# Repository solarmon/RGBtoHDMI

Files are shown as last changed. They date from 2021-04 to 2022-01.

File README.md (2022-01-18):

# RGBtoHDMI
RGBtoHDMI Projects

Various PCB projects based on c0pperdragon's Amiga adapter for hogetlet67's RGBtoHDMI solution to provide a HDMI output from the Denise chip digital signals on Amiga computers.

https://github.com/c0pperdragon/Amiga-Digital-Video

https://github.com/hoglet67/RGBtoHDMI

## Issues and Questions

Any issues or questions, please raise a ticket in the **Issues** section:

https://github.com/solarmon/RGBtoHDMI/issues

## Requirements

* Any Raspberry Pi Zero variant, but please note the following:
 - Raspberry Pi Zero 1.3 (original, no wireless, without a header, typically only one per purchase allowed)
 - Raspberry Pi Zero W (with **Wireless**, no header)
 - Raspberry Pi Zero WH (with **Wireless**, with **Header**)
* HDMI adapter/cable: 
 -The Raspberry Pi Zero comes with a **mini-HDMI** interface.
 - This needs needs to be mounted somewhere on, or passed through, the case.

## Audio not supported

The current RGBtoHDMI solutions do not support audio.

You will need to get audio to the HDMI display using some other method.

## OCS Display Modes Only

Only **OCS** display modes are supported, even when an ECS Denise is used.

**ECS** or **AGA** display modes are **not supported**.

## RGBtoHDMI Firmware for Raspberry Pi Zero

The official RGBtoHDMI firmware for the Raspberry Pi Zero can be downloaded from:

https://github.com/hoglet67/RGBtoHDMI/releases

Extract the zip file to the root of the micro-SD card.

Beta releases from IanSB can be downloaded from: 

https://github.com/IanSB/RGBtoHDMI/releases

These releases are sometimes required for certain features to work.

---
## CPLD Based Designs ##

These CPLD based boards are based on RGBtoHDMI CPLD design by LinuxJedi:

https://github.com/LinuxJedi/AmigaRGBtoHDMI

These don't require a Denise OCS/ECS jumper and have three menu button support.

I have added FF OSD integration support to the board.

A Quick Start Guide for these CPLD boards cane be found at:

https://github.com/solarmon/RGBtoHDMI/wiki/RGBtoHDMI-CPLD-Quick-Start-Guide

### RGBtoHDMI Amiga Denise DIP CPLD Rev 1.1 ###

More details and design files:

Rev 1.1: https://github.com/solarmon/RGBtoHDMI/tree/main/CPLD/RGBtoHDMI%20Amiga%20Denise%20DIP%20CPLD%20Rev%201.1

Rev 1.1 adds an optional additional right-angle push button for BT1.

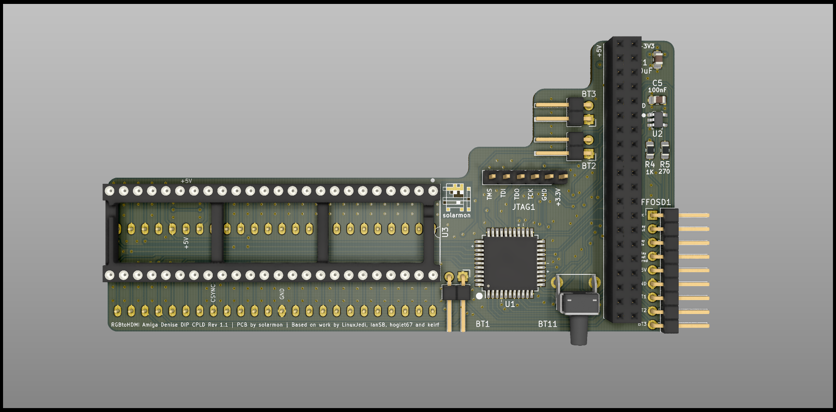
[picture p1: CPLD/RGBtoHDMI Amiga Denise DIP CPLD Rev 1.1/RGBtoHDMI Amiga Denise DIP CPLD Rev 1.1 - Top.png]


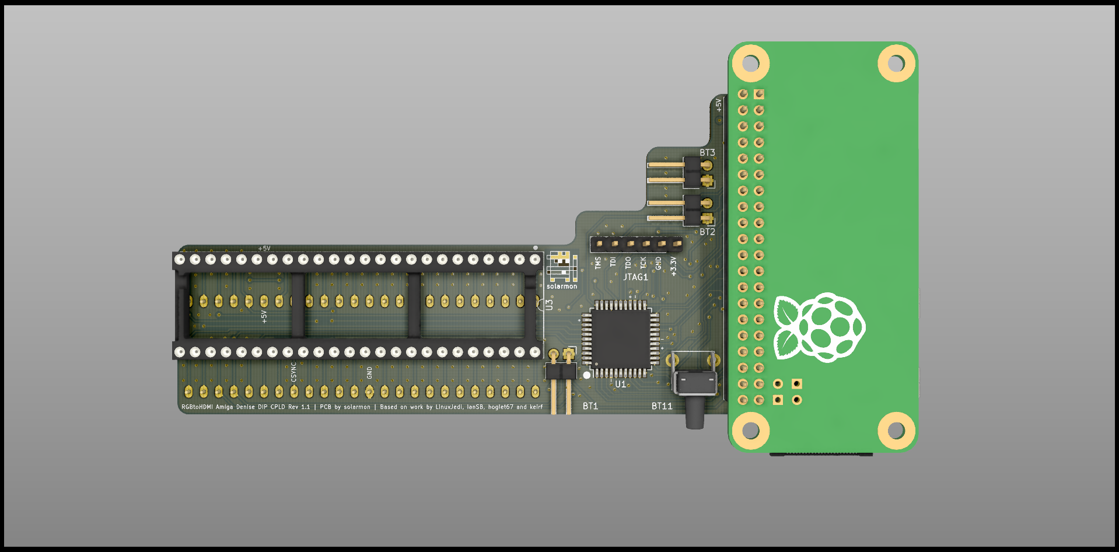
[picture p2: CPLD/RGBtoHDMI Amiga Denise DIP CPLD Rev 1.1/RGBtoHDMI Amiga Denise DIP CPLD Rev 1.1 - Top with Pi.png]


Older revisions:

Rev 1.0: https://github.com/solarmon/RGBtoHDMI/tree/main/CPLD/RGBtoHDMI%20Amiga%20Denise%20DIP%20CPLD

## CPLD and FFC Based Designs ##

These CPLD based boards are based on the excellent RGBtoHDMI CPLD design by LinuxJedi:

https://github.com/LinuxJedi/AmigaRGBtoHDMI

These don't require a Denise OCS/ECS jumper and have three menu button support.

I have added FF OSD integration support to the board.

I have used an FFC connector design to allow for different breakout hats for different Denise packages (PLCC and DIP).

### RGBtoHDMI Amiga Denise CPLD FFC Rev 1.1 ###

More details and design files:

Rev 1.1: https://github.com/solarmon/RGBtoHDMI/tree/main/CPLD/RGBtoHDMI%20Amiga%20Denise%20CPLD%20FFC%20Rev%201.1

Rev 1.1 adds an optional additional right-angle push button for BT1.

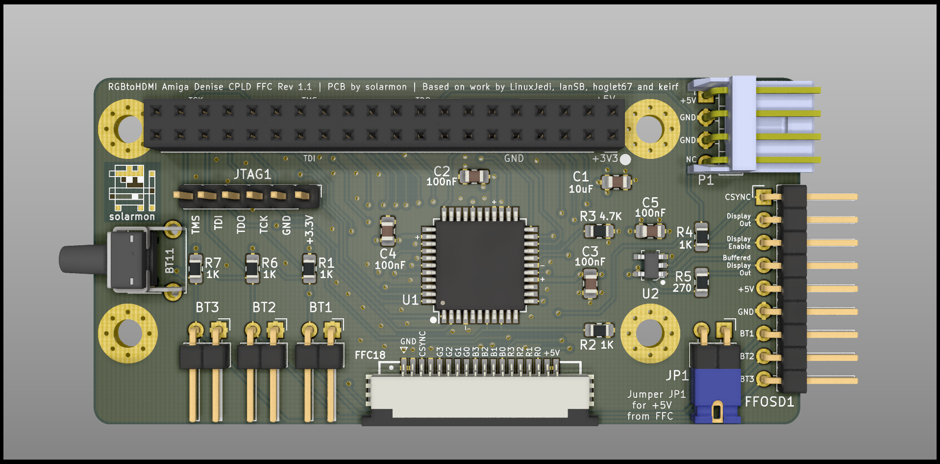
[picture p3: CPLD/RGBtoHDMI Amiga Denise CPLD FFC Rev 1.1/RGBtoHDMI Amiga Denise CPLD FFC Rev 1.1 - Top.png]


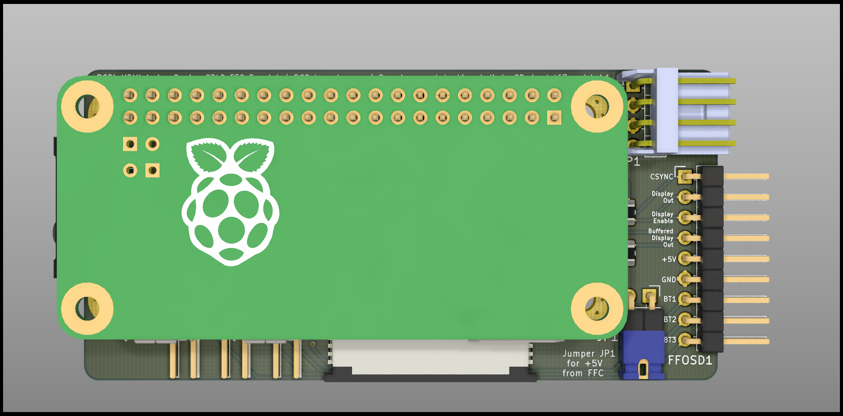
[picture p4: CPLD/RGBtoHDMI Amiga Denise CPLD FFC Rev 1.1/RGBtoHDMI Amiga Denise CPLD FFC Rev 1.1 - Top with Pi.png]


Older revisions:

Rev 1.0: https://github.com/solarmon/RGBtoHDMI/tree/main/CPLD/RGBtoHDMI%20Amiga%20Denise%20CPLD%20FFC

### RGBtoHDMI Amiga Denise PLCC SMT Breakout FFC ###

More details and design files: https://github.com/solarmon/RGBtoHDMI/tree/main/CPLD/RGBtoHDMI%20Amiga%20Denise%20PLCC%20SMT%20Breakout%20FFC

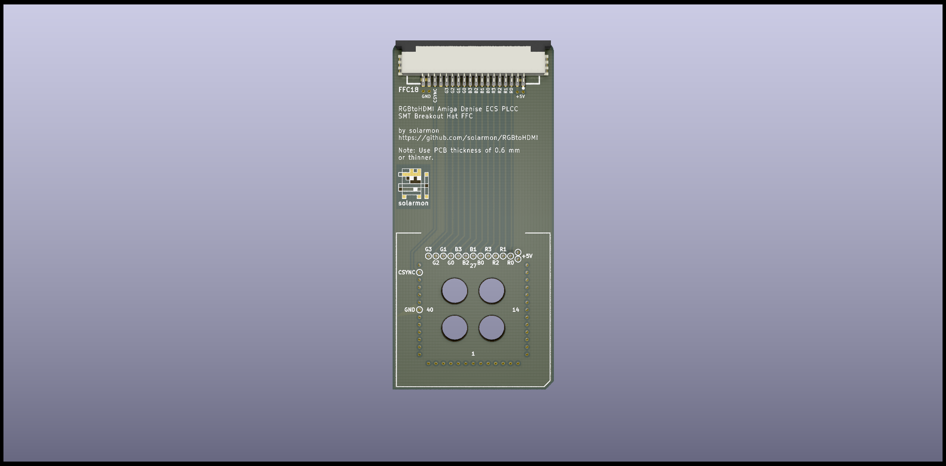
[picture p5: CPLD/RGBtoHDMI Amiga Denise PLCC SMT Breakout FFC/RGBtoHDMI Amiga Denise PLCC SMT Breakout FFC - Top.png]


### RGBtoHDMI Amiga Denise DIP Breakout FFC ###

More details and design files: https://github.com/solarmon/RGBtoHDMI/tree/main/CPLD/RGBtoHDMI%20Amiga%20Denise%20DIP%20Breakout%20FFC

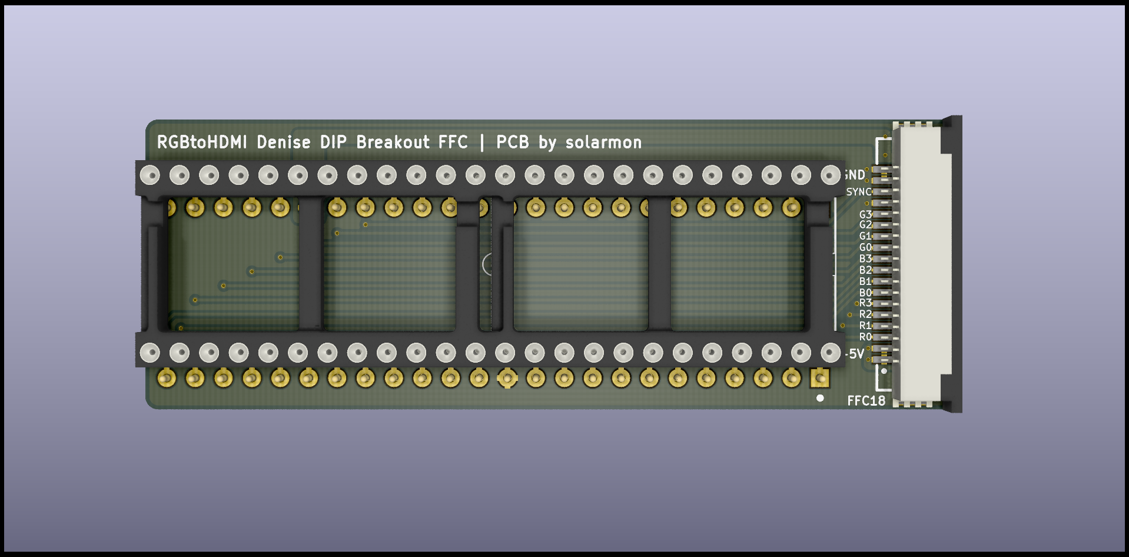
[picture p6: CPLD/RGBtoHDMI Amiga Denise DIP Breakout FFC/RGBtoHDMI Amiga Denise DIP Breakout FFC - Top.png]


### FF OSD Adapter - Rev 2 ##

More details and design files: https://github.com/solarmon/FlashFloppy/tree/main/FF%20OSD%20Adapter%20-%20Rev%202

The CPLD based RGBtoHDMI boards support FlashFloppy OSD integration and this is made easier with the FF OSD Adapter Rev 2 adapter.



---

## Amiga Denise DIP Adapter v2++

KiCAD design files:

https://github.com/solarmon/RGBtoHDMI/tree/main/RGBtoHDMI%20Amiga%20Denise%20-%20v2%2B%2B%20by%20solarmon

Based on on c0pperdragon's v2 adapter

https://github.com/c0pperdragon/Amiga-Digital-Video

https://github.com/hoglet67/RGBtoHDMI/tree/master/kicad_AmigaAdapter/V2



Tweaks and additions:

* Tweak to mask clearances
* Top and bottom ground plane
* Removes +3.3V regulator and uses the Raspberry Pi Zero +3.3V regulator
* Optional delay on PiCLK signal
* Support for FlashFloppy OSD

**Note**: The optional delay circuit (**U4**) for the **PiCLK** signal does not seem to do anything, so it is redundant and not required (but **JP2** still needs to be set to '**Normal PiCLK**'). It will be removed from future versions.

FlashFloppy OSD support is best used with the FlashFloppy OSD Blue Pill adapter at:

https://github.com/solarmon/FlashFloppy/tree/main/FF%20OSD%20Adapter



## Amiga Denise DIP Adapter v2++ Rev 2

KiCAD design files:

https://github.com/solarmon/RGBtoHDMI/tree/main/RGBtoHDMI%20Amiga%20Denise%20-%20v2%2B%2B%20by%20solarmon%20-%20Rev%202





This rev 2 design removes the redundant delay circuit using logic inverters, but adds the option to add a 47pF cap to the PiCLK line.

## Amiga Denise DIP Adapter - With Pi Relocation - Rev 1

**Note:** This is the **Rev 1** design - see further down for the **Rev 2** design.

**WARNING:** Uses an **SMT** socket header for the Raspberry Pi Zero

KiCAD design files:

https://github.com/solarmon/RGBtoHDMI/tree/main/RGBtoHDMI%20Amiga%20Denise%20-%20solarmon

A complete PCB redesign of the Amiga RGBtoHDMI v2 adapter by c0pperdragon.



Features:

* Raspberry Pi relocated to sit above the Odd CIA chip
* Use the Raspberry Pi Zero +3.3V regulator
* Optional delay on PiCLK signal
* Support for FlashFloppy OSD
* Uses an **SMT** socket header for the Raspberry Pi Zero

FlashFloppy OSD support is best used with the FlashFloppy OSD Blue Pill adapter at:

https://github.com/solarmon/FlashFloppy/tree/main/FF%20OSD%20Adapter



**Note**: The optional delay circuit (**U4**) for the **PiCLK** signal does not seem to do anything, so it is redundant and not required (but **JP2** still needs to be set to '**Normal PiCLK**'). It will be removed from future versions.

**Note**: **IMPORTANT** On this board design the Raspberry Pi Zero faces **up**. This is different from the original RGBtoHDMI v2 adapter where it faces **down**. This means the header is on the other side, so any existing Raspberry Pi Zero will need to be modified accordingly. **This will be changed in the next version to face down, so that existing Raspberry Pi Zeros can be used.**



**Note**: This board design still uses the smaller **TSSOP** package from the original RGBtoHDMI adapter. The next version will use the larger **SOIC** package.

## Amiga Denise DIP Adapter - With Pi Relocation - Rev 2 (TSSOP)

**WARNING:** Uses an **SMT** socket header for the Raspberry Pi Zero

KiCAD design files:

https://github.com/solarmon/RGBtoHDMI/tree/main/RGBtoHDMI%20Amiga%20Denise%20-%20solarmon%20-%20Rev%202%20-%20TSSOP

**Note:** This Rev 2 design has the Pi Zero facing **DOWN** (instead of facing **UP** in rev 1)



This rev 2 design removes the redundant delay circuit using logic inverters, but adds the option to add a 47pF cap to the PiCLK line.

This design still uses the smaller **TSSOP** chip package.

## Amiga Denise DIP Adapter - With Pi Relocation - Rev 2 (SOIC)

**WARNING:** Uses an **SMT** socket header for the Raspberry Pi Zero

KiCAD design files:

https://github.com/solarmon/RGBtoHDMI/tree/main/RGBtoHDMI%20Amiga%20Denise%20-%20solarmon%20-%20Rev%202%20-%20SOIC

**Note:** This Rev 2 design has the Pi Zero facing **DOWN** (instead of facing **UP** in rev 1)

**Note:** This version uses the larger SOIC chip package



This rev 2 design removes the redundant delay circuit using logic inverters, but adds the option to add a 47pF cap to the PiCLK line.

This design still uses the larger **SOIC** chip package, making it easier to hand solder.

## Amiga Denise PLCC Adapter

KiCAD design files:

https://github.com/solarmon/RGBtoHDMI/tree/main/RGBtoHDMI%20Amiga%20Denise%20ECS%20PLCC

Based on c0pperdragon's RGBtoHDMI Small adapter.

https://github.com/hoglet67/RGBtoHDMI/tree/master/kicad_AmigaAdapter/Small

This is a PLCC hat version of the RGBtoHDMI Small adapter that sits directly on top of the Denise PLCC chip.

This is for the Amiga A600 Denise ECS chip. However, the RGBtoHDMI solution only supports **OCS** modes, not **ECS** modes:

https://github.com/c0pperdragon/Amiga-Digital-Video#compatibility

**Note**: It uses the larger **SOIC** chip package, rather than the smaller **TSSOP** chip package.



Features:

* No soldering required - sits directly on top of the Denise PLCC chip
* Integrated RGBtoHDMI solution on same board.

**Note**: The +**5V** and **GND** traces going to the Denise PLCC chip is very thin. Header **JP1** is provided for +**5V** and **GND**. It is recommedned that power is provided to the board using this.

**Note**: The PLCC socket on this board needs some midifications to allow it to sit properly. See LemaruX's guide on the 68K PLCC socket rework that also applies to the Denise PLCC socket: 

https://github.com/LemaruX/Amiga-A600-68k-PLCC2DIP-v2/blob/main/PLCC-Rework.md

**Note**: This design will not work with most expansion boards in the A600 as it will spoil with it. Check compatibility before you commit to using/buying this board.

**Note**: On this board, the Raspberry Pi Zero faces **down**:



## RGBtoHDMI Pi Relocator Adapter  - Type A

KiCAD Design Files: https://github.com/solarmon/RGBtoHDMI/tree/main/RGBtoHDMI-Adapter%20Type%20A

This is a Pi relocator adapter that will flip it over to sit over RGBtoHDMI board.

**Note**: **IMPORTANT** The Raspberry Pi Zero is flipped over. To keep the profile low, you need to solder the Raspberry Pi Zero directly to the adapter.





## RGBtoHDMI Pi Relocator Adapter  - Type B Rev 2

KiCAD design Files: https://github.com/solarmon/RGBtoHDMI/tree/main/RGBtoHDMI-Adapter%20Type%20B%20Rev%202

This is a Pi relocator adapter and has an optional 47pF (or other value) location to reduce any sparkles.



## RGBtoHDMI Pi Relocator Adapter  - Type C Rev 2

KiCAD design Files: https://github.com/solarmon/RGBtoHDMI/tree/main/RGBtoHDMI-Adapter%20Type%20C%20Rev%202

This is a Pi relocator adapter and has an optional 47pF (or other value) location to reduce any sparkles.



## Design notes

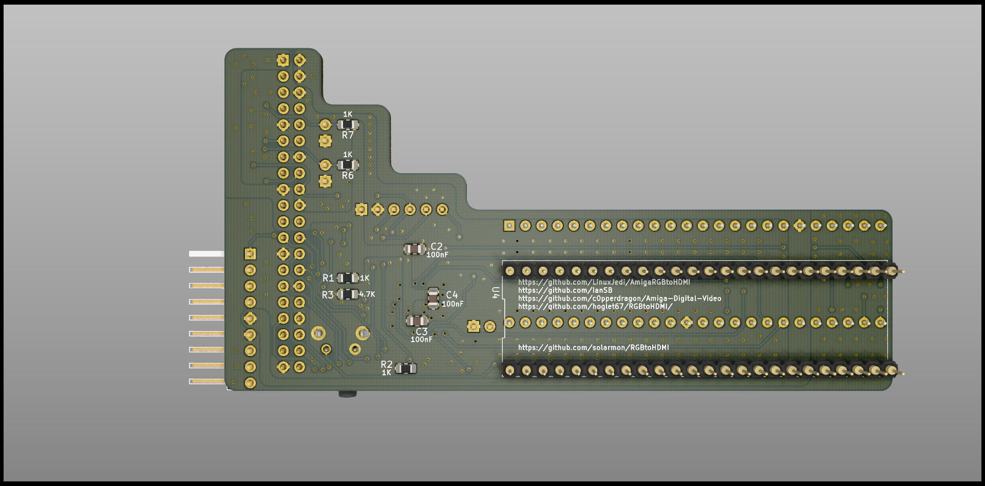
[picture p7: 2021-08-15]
CPLD/RGBtoHDMI Amiga Denise DIP CPLD Rev 1.1/RGBtoHDMI Amiga Denise DIP CPLD Rev 1.1 - Bottom.png

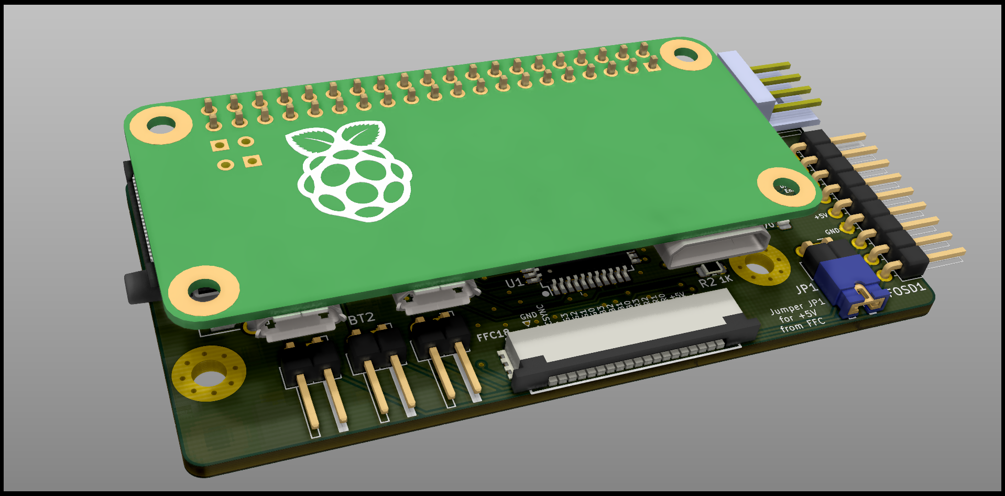
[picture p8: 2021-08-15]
CPLD/RGBtoHDMI Amiga Denise CPLD FFC Rev 1.1/RGBtoHDMI Amiga Denise CPLD FFC Rev 1.1 - Top Angled with Pi.png

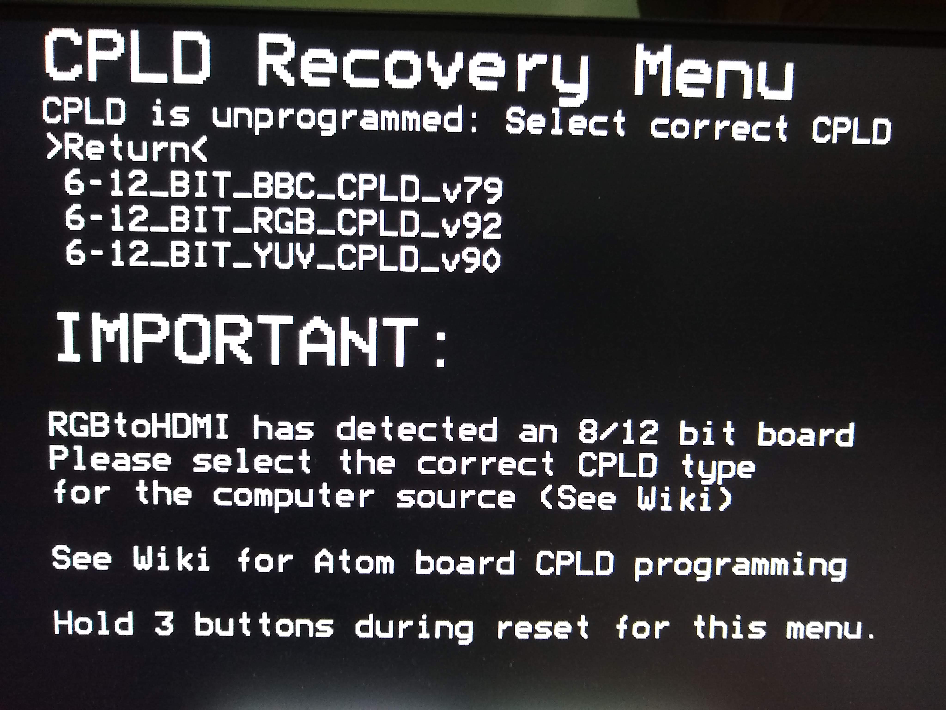
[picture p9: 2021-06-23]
CPLD/CPLD-Recovery-Menu.jpg

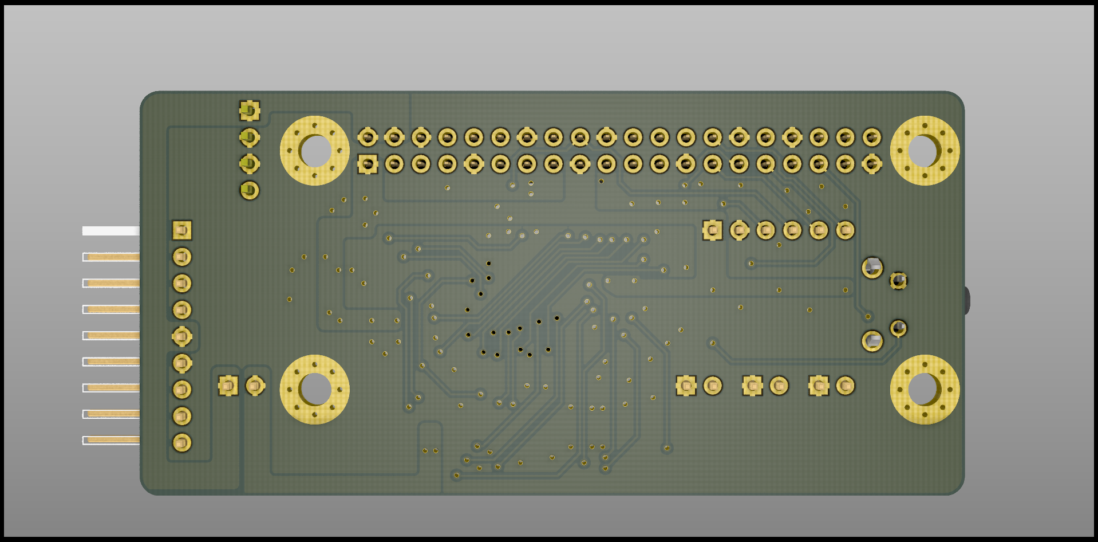
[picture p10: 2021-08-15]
CPLD/RGBtoHDMI Amiga Denise CPLD FFC Rev 1.1/RGBtoHDMI Amiga Denise CPLD FFC Rev 1.1 - Bottom.png

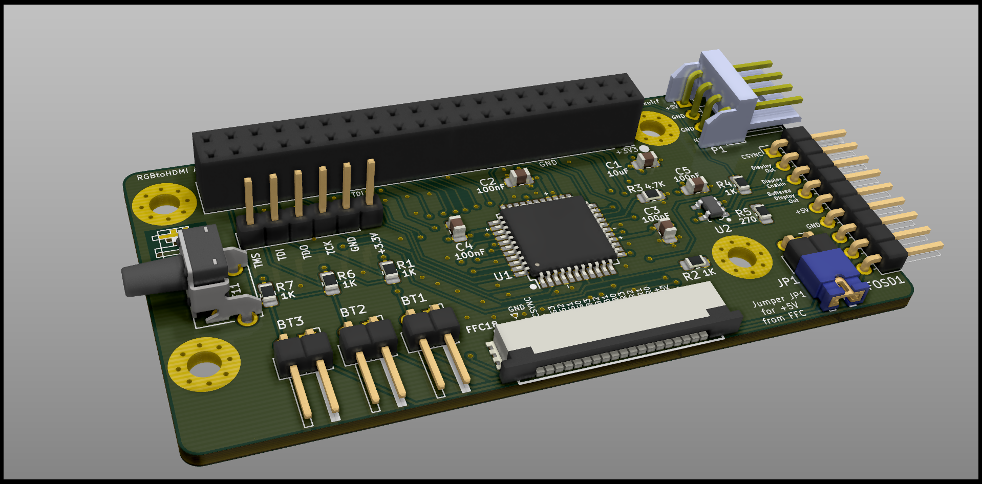
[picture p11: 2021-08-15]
CPLD/RGBtoHDMI Amiga Denise CPLD FFC Rev 1.1/RGBtoHDMI Amiga Denise CPLD FFC Rev 1.1 - Top Angled.png

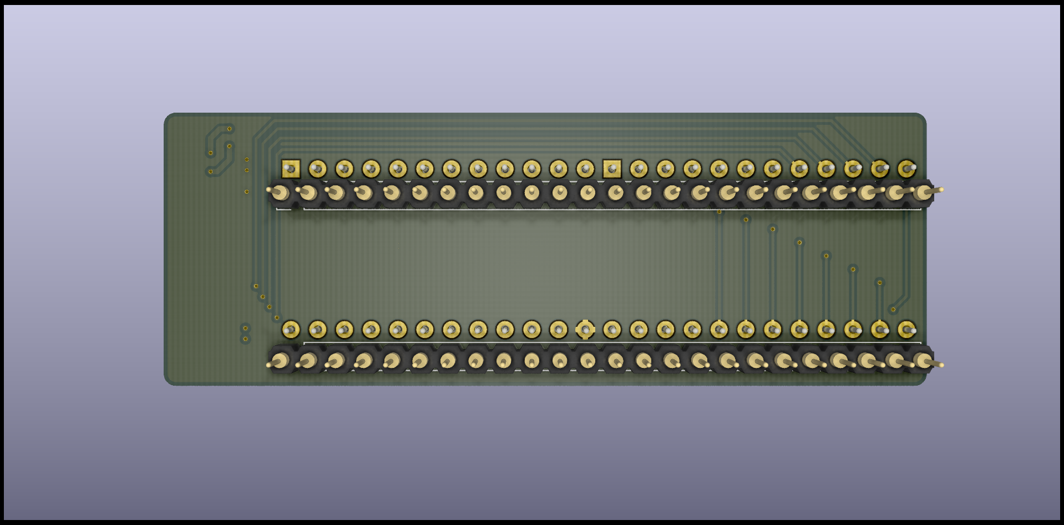
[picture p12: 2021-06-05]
CPLD/RGBtoHDMI Amiga Denise DIP Breakout FFC/RGBtoHDMI Amiga Denise DIP Breakout FFC - Bottom.png

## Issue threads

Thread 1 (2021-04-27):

RGBtoHDMI PLCC model

krug3rf, 2021-04-27:
Hi @solarmon ,

I just made my first model and I have an issue, I just see the splashcreen (4 color from start) and nothing more...
I use a LVC574A**D**, do you think it could be the problem ?!
I don't use P1, but I use a external alimentation for testing, but no change.

KR
Fred

solarmon, 2021-04-28:
Hi @krug3rf

I use the following logic chips on my boards:

U2/U3: Texas Instruments SN74LVC574ADW Octal D Type Flip Flop IC, 3-State, 20-Pin SOIC
U1: Texas Instruments SN74LVC86ADR, Quad 2-Input XOR Logic Gate, 14-Pin SOIC

What is the full part number of your chips?

Can you show how you have built it - especially the PLCC socket - this has to be in the correct orientation.

Use a multimeter to check the identified Denise pins (the ones circled) to where they should be on the motherboard - especially the CSYNC and 7M signals.

krug3rf, 2021-04-28:
All continuties from U1/U2/U3 have been tested and are OK.
I check again to answer when I will back home (I'm at office) ;)

solarmon, 2021-04-30:
@krug3rf Do you still have this issue? If you can provide more information then I can try to help you resolve it.

krug3rf, 2021-04-30:
Hi, I'm back home this weekend and do it ;)
thanks for your help :)

Le ven. 30 avr. 2021 à 09:32, solarmon ***@***.***> a écrit :

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

krug3rf, 2021-04-30:
I have a question for you about the PLCC 52, do you use sandpaper or a hand
tool (like a dremel) to modify it ?
Your model is an Augat PCS-052A or a generic ?

Le ven. 30 avr. 2021 à 10:08, Frédéric Campos ***@***.***> a
écrit :

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

solarmon, 2021-04-30:
@krug3rf For the PLCC-52socket mod, all I did was to cut the plastic standoffs inside the socket. I just use some small wire side cutters, but it is not so good - so a Dremel type tool is probably the better/recommended option.

I don't know what 'model' my PLCC-52 socket is - it is just a no brand one that I purchased on eBay.

krug3rf, 2021-05-01:
Î'm exiting ^^
Can you share some beta previews of your new projects (I keep this for me,
promise :p) ?

Le ven. 30 avr. 2021 à 23:54, solarmon ***@***.***> a écrit :

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

krug3rf, 2021-05-01:
*excited lol

Le sam. 1 mai 2021 à 11:55, Frédéric Campos ***@***.***> a
écrit :

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

solarmon, 2021-05-02:
@krug3rf I can give you some teaser pictures!

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

krug3rf, 2021-05-02:
Sexy ^^
so with this model Furia accelerator could be added ?

Le dim. 2 mai 2021 à 11:57, solarmon ***@***.***> a écrit :

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

solarmon, 2021-05-02:
CPLD solution design is from LinuxJedi, I'm just re-mixing it to a new footprint.

I have not got a Furia accelerator to test, so I don't know if this PLCC FFC hat design will be low profile enough.

Closed 2021-04-30.

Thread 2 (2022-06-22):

Single Button Mode not working

tkurbad, 2022-06-22:
Hi,

I built one of these boards and it's working perfectly so fine. The problems I had with the original design (i.e. purple sparkles) are gone. Picture is crisp and clear.

However, I can't get single button mode to work as expected. It seems inverted, i.e. a long press turns on/off scanlines, while a short press displays the OSD. However, while the OSD is showing, the next press is always considered short, thus closing the OSD again.

Here's my Profiles/Default.txt

``
sampling2=6,6,6,6,6,6,6,0,1,0,12,0,0,0,0,0,0,0,0,0,100,256,100,256,100,256,256,256
geometry2=140,26,520,256,576,288,3,4,1,0,12000000,768,5000,312,4,0,2
sampling=3,3,3,3,3,3,3,0,0,0,5,0,0,0,0,0,0,0,0,0,100,256,100,256,100,256,256,256
geometry=180,29,640,256,768,288,1,2,1,1,16000000,1024,5000,312,4,0,0
auto_switch=0
timing_set=0
palette=RGB
palette_control=0
ntsc_colour=0
ntsc_phase=0
ntsc_quality=0
tint=0
saturation=100
contrast=100
brightness=100
gamma=100
teletext_deinterlace=6
teletext_scaling=1
normal_deinterlace=0
ffosd_overlay=0
normal_scaling=0
swap_aspect=0
output_colour=0
output_invert=0
scanlines=0
scanline_level=6
powerup_message=1
crop_border=0
screencap_size=0
border_colour=0
font_size=1
vsync_indicator=0
genlock_mode=0
genlock_line=50
genlock_speed=2
genlock_adjust=0
num_buffers=0
hdmi_standby=0
overclock_cpu=0
overclock_core=0
overclock_sdram=0
button_reverse=0
debug=0
keymap=13232
actionmap=012453
return=0
single_button_mode=1
cpld_firmware_dir=/cpld_firmware/6-12_bit
``

Can you tell what might be wrong? This happens on both stable and beta releases.

Thanks,
Torsten

tkurbad, 2022-06-22:
Okay, nevermind, it's working perfectly fine. Just saw that I edited the wrong Default.txt ;-)

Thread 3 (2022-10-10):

Rev 2 board doesn't fit on Rev 3 Amiga 500 motherboards

MatGrump, 2022-10-10:
The inductor LF1 is lower on Rev 3 boards and doesn't allow for installation of the REV 2 RGD2HDMI board. See attached images

https://imgur.com/a/YwSwP5C

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

solarmon, 2022-10-10:
Hi,

That is not one of my RGBtoHDMI board for the A500.

It looks like it is from PM Developments:

https://www.facebook.com/PMDevelopments/
https://www.instagram.com/pmdevelopments/

You'll have to raise that with that developer.

MatGrump, 2022-10-10:
yes sorry. I noticed after i posted it. It looks like yours has taken this into consideration.

solarmon, 2022-10-10:
No worries. I can't remember whether I actually tested with a rev 3 board - I'll have to dig it out to check!

MatGrump, 2022-10-10:
No problem, if you need me to measure anything please let me know.

solarmon, 2022-10-10:
Actually, I don't have a rev 3. I was thinking of a rev 5, which I do have.

Using an image I found of the rev 3, I overlayed an image of my latest RGBtoHDMI A500 board, and that looks like it wouldn't fit either:

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

The coil is definitely much lower in a rev 3 board!

I can think of three options you might have:

1. Use the original RGBtoHDMI board design, which doesn't have a pi relocator.

2. Use my RGBtoHDMI Amiga Denise CPLD FFC Rev 1.1 (https://github.com/solarmon/RGBtoHDMI#rgbtohdmi-amiga-denise-cpld-ffc-rev-11) with a RGBtoHDMI Amiga Denise DIP Breakout FFC (https://github.com/solarmon/RGBtoHDMI#rgbtohdmi-amiga-denise-dip-breakout-ffc).

3. Replace the Denise socket on the RGBtoHDMI board with ones with longer pins that pass straight through. This shift down the board a bit, which MIGHT work. I use such a socket for my RGBtoHDMI CDTV solution and it also makes it a bit lower profile.

solarmon, 2022-10-10:
The latest LinuxJedi design, looks like it should support rev 3 motherboards:

MatGrump, 2022-10-10:
Some good solutions. I have the option to return this board and get another which is probably what I will do for now while I think about a different solution. The LinuxJedi looks like the simplest way forward but they are out of stock.

Thanks for all the help, even though it wasn't even your board. Very much appreciated.

Retrofletch, 2022-11-21:
I made a longer version based on the old linuxjedi version that i think also would fit.
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

and there is also this version that should fit:
https://github.com/nobodyisinocent/RGBtoHDMI#tiny-rgb2hdmi-cpld-design-

Just for future reference :)

ehalebi, 2023-08-19:
@solarmon is it possible to make a Extralong version of CPLD 500 PCB with your FF addons? Retrofletch has one, but without FF OSD support.

regards

Retrofletch, 2023-08-19:
It would be quite easy to make solarmons design a bit longer to fit but i just dont have the time at this moment

ehalebi, 2023-08-19:
@solarmon is that something you could do?
Maybe 5-8cm longer. So a lot of people got a Gotek drive and want to add also HDMI to their A500s. And if you also got an accelerator card sitting on a 90 degree Relocator, than this will be the best RGB2HDMI Solution .

only thing missing is still audio embedder/injector for all of them.

ehalebi, 2023-08-19:
I have bought an audio Inserter for installing it internally in my A500
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

solarmon, 2023-08-19:
@ehalebi

It can certainly be done, but unfortunately, this is not high my list (if at all). Probably the only reason I would work on this again, is to create a PLCC version of it.

Regards,

Mon

ehalebi, 2023-09-11:
Do I need to buy software to do this?

regards

solarmon, 2023-09-12:
@ehalebi

> Do I need to buy software to do this?
>
> regards

To do what?

solarmon, 2023-09-12:
@ehalebi

The PCB design was done using KiCAD, which is an open source application - https://www.kicad.org/

But be warned - it is a very steep learning curve if you don't already have experience in PCB design.

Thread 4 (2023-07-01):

Getting a no sync issue

luvwagn, 2023-07-01:
I'm wondering if instructions are still correct, regarding the amiga_cpld folder etc.

My cdtv rgbtohdmi is working, amiga is working via db23 video port, but I can't get a sync signal?

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

solarmon, 2023-07-02:
Hi,

For the purpose of this ticket, please provide some context:

* What RGBtoHDMI adapter have you got?
* Where did you buy it from (or whether you built it yourself)?
* Which Amiga it is being used on, and what Denise chip does it have?

Please provide some clear pictures of your RGBtoHDMI board/adapter and setup.

luvwagn, 2023-07-02:
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

None of the above results in a solid image, but I can see the content changing from cdtv insertion animation, to wb3.2.x (ntsc mode)
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

Retrofletch, 2023-07-05:
I sent him a copy of my own SD card i use for testing these, it will help rule out issue with his software setup.
I also asked him to test contuinity between csync on both ribbon cable connectors to rule out bad cable / connection.
if these are not issue im gonna assume i borked something up hardware wise, i always test before send ofcourse but it could have been a badly soldered connection or similar that got loose in shipping or while installing. it happens =/

solarmon, 2023-07-05:
@luvwagn

Apologies for the delay in replying.

For the Denise adapter FFC connector, it looks different my normal design - which has the contacts at the bottom - so the FFC flex cable has the contacts at the bottom and the blue side facing up (maybe @Retrofletch can confirm). This also the same at the RGBtoHDMI board end too.

luvwagn, 2023-07-05:
As mentioned in email, it depends on the connectors. With blue up at both ends, I get a black screen. With blue down at both ends, I get some correct  but garbled output.

Your design has the cables under black connectors and blue up, but different choice of connectors like used here means black underneath and blue down.

solarmon, 2023-07-06:
@luvwagn

All I can suggest is to check the flex connector pins on the Denise adapter and on the RGBtoHDMI board; and also check the pins on the CPLD chip- check that there are no cold joints and they are not shorted together.

luvwagn, 2023-07-28:
@solarmon - the fw releases from Ian / hoglet etc have an "Amiga_CPLD" folder - is any action required regarding that folder, on your design?  It references "LinuxJedi" designs as needing things done regarding that folder...

luvwagn, 2023-07-28:
> @luvwagn
>
> All I can suggest is to check the flex connector pins on the Denise adapter and on the RGBtoHDMI board; and also check the pins on the CPLD chip- check that there are no cold joints and they are not shorted together.

Have done so - there is full CSYNC continuity between the denise pin, ribbon header on Denise Board, and ribbon header on RGB2HDMI board.  Checked other connections as well, have full continuity

solarmon, 2023-07-28:
@luvwagn

Please point to where it "needing things done regarding that folder" - I'm not sure what you mean.

You seem to have the software running correctly - so I'm not suspecting that. It just seems the signal to/from the CPLD chip is possibly shorted or not connected somewhere. Sorry, there is nothing else I can suggest.

luvwagn, 2023-07-28:
There is an amiga_cpld_readme folder at the root of the zip file.  it doesn't matter if i perform those actions or not, i get the same "no sync found" problem.  I believe those actions just set the defaults to 1-button mode and an Amiga setting.

I checked the CSYNC signal from U1 Pin 3+4 to Denise to Denise Carrier PCB with ribbon connector, to RGB2HDMI board, to CPLD pin.  I have continuity through the entire path.

Is it possible somehow that CSYNC is incorrect?  That doesn't make sense to me, as regular RGB output is working...
________________________________
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

Retrofletch, 2023-09-06:
It works just fine but i tend to respond only once i have an update, you can also reach me by mail retrofletch@outlook.com so we dont annoy solarmon by all this offtopic.

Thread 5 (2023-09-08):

pixelation issues with rgb2hdmi board

pruttm, 2023-09-08:
I have installed the rpg2hdmi board below in my Rev 5 Amiga 500.  The display has incorrect pixels sprinkled over the display and some of them flash.  I also noticed the display can change when I press on the Denise chip. I could order some contact cleaner if it is a connectivity issue. Alternatively, are there settings I should be adjusting to clear this up?

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

solarmon, 2024-11-03:
@pruttm

Sorry, I've only just seen this ticket.

Where did you purchase this RGBtoHDMI board from, and which exact model/version?

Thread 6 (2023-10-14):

RPi not booting with CPLD RGB to HDMI

bmthr, 2023-10-14:
Hi all,

My problem is that my RPi ZERO WH not working wiith CPLD RGB to HDMI adapter on Amiga 500. RPi 1.3 work well with this adapter and RPi WH working well with TTL adapter.
RPi WH if not connected to CPLD adapter board show menu _CPLD not fitted_, but when I connect it to CPLD board stuck on empty black screen.

Did I miss some settings? Any help about my problem?

Thank You!

bmthr, 2023-10-16:
I build it by myself, I build almost 200 boards TTL and CPLD and necet found problem like this...

Pictures if CPLD board and RPi attached...
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

bmthr, 2023-10-16:
When I connect all to Amiga, screen is black, there is no any message or info on screen. If I connect only RPi to HDMI and connect power supply I get message CPLD not fitted. As I say before, when I put this RPi to Small TTL RGBtoHDMI adapter all is working well

solarmon, 2023-10-16:
Hi @bmthr

This is not one of my RGBtoHDMI board designs - it is one from LinuxJedi.

Normally, when I have issues with the a CPLD based RGBtoHDMI board, it is because there is a cold solder joint on one of the pullup resistors or capacitors, or (a cold joint or short) on a CPLD pin.

bmthr, 2023-10-16:
Yes, I know that, but I tested this Rpi with other CPLD board (have it 3 on stock now) and problem is same, but all boards work fine with RPi v1.3

solarmon, 2023-10-16:
What RGBtoHDMI firmware version are you using?

Get the latest stable version from:

https://github.com/hoglet67/RGBtoHDMI/releases

or the latest beta versions from:

https://github.com/IanSB/RGBtoHDMI/releases

I've have also come across issues where the CPLD RGBtoHDMI board did not work until you tried a different microSD card on the Pi.

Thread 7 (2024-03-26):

STM Binary

venice1200, 2024-03-26:
Hi,
I am going to build your RGB2HDMI FlashFloppy OSD Project but I don’t know how to build the firmware for the STM.

Is there a prebuild binary available from your end?

And do you have any plans plans to patch the current OSD Version from keirf with your changes?

Many Thanks

solarmon, 2024-03-26:
Hi,

Do you mean my forked repo for OSD at?:

https://github.com/solarmon/FF_OSD

If I remember correctly, the only change I did was to add the RGBtoHDMI 3-button example (in https://github.com/solarmon/FF_OSD/blob/master/src/default_config.c):

https://github.com/solarmon/FF_OSD/commit/b5f8fc9119af0d06347212f83702bbfb92cdf91b

So you could probably easily make this change to the source file of the original repo at https://github.com/keirf/flashfloppy-osd

Sorry, I don't have any pre-built binaries. I can't even remember how to build it without looking in to it again.

solarmon, 2024-03-26:
The build guide from keirf's flashfloppy-osd repo is at:

https://github.com/keirf/flashfloppy-osd/wiki/Building-From-Source

venice1200, 2024-03-27:
...means the RGB2HDMI OSD via HDMI works out of the box when i build and use your hardware, even with an unmodified Software from keirf?

solarmon, 2024-03-27:
Well, it will work but without the three button integration - so you cannot use the keyboard to control the RGBtoHDMI menu (using F1, F2 and F3 - or whatever button you assign in `default_config.c`)

solarmon, 2024-03-27:
I have updated the README (for https://github.com/solarmon/FlashFloppy/tree/main/FF%20OSD%20Adapter%20-%20Rev%202) to mention the button mapping changes required, and link to how to build the Blue Pill firmware:

https://github.com/solarmon/FlashFloppy/blob/main/FF%20OSD%20Adapter%20-%20Rev%202/README.md#ff-osd-firmware

venice1200, 2024-03-27:
I will try!

Many Thx

venice1200, 2024-04-02:
Hi again,
C1 is marked as Unipolar 10uF Capacitator. But the footprint picture looks like a "normal" Ceramic one.
Is a bipolar one fine as well?

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

Are all SMD Parts 0805?

Cheers

venice1200, 2024-05-05:
I got the boards and the CPLD and the other parts solderred.
I have checked every conection to the PI, everthing looks fine, but the CPLD can't be programmed.

```
8/12 bit board detected
...
CPLD  Design: 3-12_BIT_BBC
CPLD Version: c.f
```
Any idea what can be the problem?

Full log attached.

[2024-05-05_Serial_Log.txt](https://github.com/solarmon/RGBtoHDMI/files/15213682/2024-05-05_Serial_Log.txt)

solarmon, 2024-05-05:
Hi,

Which RGBtoHDMI board did you build?

Check that non of the CPLD chip pins are shorted or have dry connections. Also check the resistors and caps are OK and connected to where they should be.

venice1200, 2024-05-05:
I built a Denise Adapter v1.1.

I have already checked the whole board as good as possible.

solarmon, 2024-05-05:
Which CPLD chip are you using - what is the exact part number and where did you get it from?

IanSB, 2024-05-05:
@solarmon

The CPLD is already programmed with some other firmware. The fix on a normal CPLD board is to cut JP1, JP2 & JP4 for first programming and then remake them. Are those jumpers present on your board?

solarmon, 2024-05-05:
@IanSB

Unfortunately, there are no such jumpers on my board design - so those tracks will need to be physically cut.

venice1200, 2024-05-06:
I am using a XC9572XL VQFP44.

TCK (44), TMS (6) and TDI (7) are connected to a dedicated PinHeader in the board.

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

@IanSB
maybe we can drive the pins up or down for reprogramming?

solarmon, 2024-05-06:
For my own future reference - details of the solder jumpers (bridged)  and what pins/signals they are for:

JP1 = GPI00 = TDI
JP2 = GPI020 = TCK
JP4 = GPI01 = TMS

These don't currently exist on any of my RGBtoHDMI board designs.

venice1200, 2024-05-06:
I think the Pins which needs to be disconnected are TCK (44), TMS (6) and TDI (7).
Not the other three pins.

Please correct me if i am wrong.

IanSB, 2024-05-06:
@venice1200
@solarmon

The pins that have to be disconnected are CLKEN, SPDATA and SPCLK which are Pins 6, 7 and 44 of the CPLD.
You have to cut the tracks going to those pins without breaking the connection between the GPIOs and TCK, TMS and TDI
Depending on the layout, this might not be easy as the tracks might be under the CPLD or cutting them also disconnects the GPIOS from the TCK, TMS and TDI pins.
The other option would be to temporarily desolder and bend up CPLD pins 6, 7 and 44.

IanSB, 2024-05-08:
@solarmon
I suggest you add those jumpers to any future revisions of your boards.
Any reason you didn't include them? The jumpers were originally added when CPLD programming was added to the project in case users accidentally programmed the Atom firmware which has the same effect but it has been useful for coping with recycled CPLDs

I have updated the wiki to cover this in more detail including how to use the 'Delete_This_File_To_Erase_CPLD.txt' feature:
https://github.com/IanSB/RGBtoHDMI/wiki/Troubleshooting

This is likely the cause of the problem with this issue too:  https://github.com/solarmon/RGBtoHDMI/issues/6

BTW can you give the latest Alpha 65G a test to see if it works with your monitor(s). It contains a HDMI audio output driver but no audio input yet!
https://github.com/IanSB/RGBtoHDMI/issues/29#issuecomment-2099613155

solarmon, 2024-05-08:
> @solarmon I suggest you add those jumpers to any future revisions of your boards. Any reason you didn't include them? The jumpers were originally added when CPLD programming was added to the project in case users accidentally programmed the Atom firmware which has the same effect but it has been useful for coping with recycled CPLDs
>

My RGBtoHDMI spinoffs were original based on the c0pperdragon and LinuxJedi designs, which didn't have these jumpers. And this is the first I've heard of this specific issue.

> BTW can you give the latest Alpha 65G a test to see if it works with your monitor(s). It contains a HDMI audio output driver but no audio input yet! [IanSB/RGBtoHDMI#29 (comment)](https://github.com/IanSB/RGBtoHDMI/issues/29#issuecomment-2099613155)

Ooh, that is interesting! I will definitely try it and will report back on that ticket.

venice1200, 2024-05-08:
Success...

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

IanSB, 2024-05-08:
@venice1200
That's great

@solarmon
> And this is the first I've heard of this specific issue.

It seems to be getting more common, as you can see from the above photo I added a message about it to the latest release although that doesn't help so much if you just get a blank screen and don't know about the three buttons or the delete file.

One other thing that just occurred to me:
There was originally a jumper JP3 which isolated the fourth programming line TDO but the additional CPLD pin it was connected to was re-used for something else and TDO is connected straight to GPIO 24 on the current revision.
However GPIO24 is now also used for the FFOSD overlay so you need to make sure that is disconnected when programming the CPLD.

solarmon, 2024-05-08:
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

Yea, this RGBtoHDMI board integrates with FF-OSD and this overlay connection is basically how FF-OSD feeds it's OSD menu to the Pi to be put into the HDMI display.

IanSB, 2024-05-08:
@venice1200
@solarmon
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
venice1200, 2024-07-02:
Hi,
finally i added all your RGBtoHDMI Boards and programmed the BluePil with the original Hex from keirf (for the moment).
But I get no OSD shown.

Question, do I need the green line from the BluePil Board to the Amiga to get the OSD shown?

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

venice1200, 2024-07-02:
I have tried with PA15 Low enabled but no success.

```
** FF OSD v1.9 **
** Keir Fraser <keir.xen@gmail.com>
** https://github.com/keirf/FF_OSD

Current config:
 Sync Polarity: Low
 Pixel Timing: 15kHz
 Display Height: Normal
 Display Output: PB15/SPI2
 Display Enable: PA15 Act.LOW
 H.Off: 42
 V.Off: 50
 Rows: 2
 Columns: 16-40

Keys:
 Space: Select
 O: Down
 P: Up
Sync lost
```

solarmon, 2024-07-03:
Hi @venice1200

You shouldn't need the RGB output signal to be connected. However, it is useful to see/check whether FF OSD is actually working on your Bluepill.

solarmon, 2024-07-03:
@venice1200

On your FF OSD Adapter board, have you got JP1 jumpered?

venice1200, 2024-07-03:
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

Yes.

venice1200, 2024-07-03:
Got it working!
Had to add a jumper at JP2 between sync (middle) and c/h sync.

Should this looks like this?
The chars look like flames.

https://github.com/solarmon/RGBtoHDMI/assets/43762187/f85cd49a-4581-460f-b4e8-a341047465d7

solarmon, 2024-07-03:
Glad you figured it out.

Unfortunately, that is the best that the FF OSD will look over the HDMI output.

venice1200, 2024-07-03:
Many man thanks for your support and all the best!

IanSB, 2024-07-03:
@venice1200

The reason it's jittery is that the pixel clock of the blue pill isn't locked to the Amiga pixel clock so it was either that or nothing.
In theory you could run the blue pill from an Amiga derived clock which would stop the jittering but so far no-one has looked at that.

solarmon, 2024-07-03:
@IanSB

Would that be a software or hardware thing, or both - to get the Blue Pill to use the Amiga clock?

venice1200, 2024-07-04:
Additionally I get problems reading data from the gotek.

Data are not correctly loaded each time.
If this happens the screen shows then below system request and the gotek is sent to the eject menu.

If remove the bluepil board it works fine again.

It can be my installation, i need to test more.

I am using flash floppy 3.42.

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

solarmon, 2024-07-04:
@venice1200

I can't seen how the Bluepill with FF OSD software could interfere with the FF on the Gotek reading ADF files.

The only connection between the Bluepill and Gotek should be the GND, 3.3V, SCL and SDA lines for I2C communications.

If it is causing FF on the Gotek to eject the ADF image then that might suggest that keyboard binding integration part is possibly interfering with it - so check the KB_CLOCK anf KB_DATA connections, and make sure you use a FF OSD firmware that supports the keyboard integration.

venice1200, 2024-07-04:
The Keyboard integration works fine for me, no problems here.

I can't tell you what causes this.

The only thing i know is that it works (for me) only without the bluepil board connected but let me a few more things.

Do you have a running OSD integration in use actually?

venice1200, 2024-07-07:
I have changed the display to another one, no change.
I use the OSD as the only i2c device I have these problems as well.
Issue opened at FlashFloppy Github: https://github.com/keirf/flashfloppy/issues/913

solarmon, 2024-10-19:
@IanSB

When cutting the JP1, JP2 and JP4 signals does this have to be done at the CPLD pin end, or can it be done at the Raspberry Pi pins end?

For example if JP1 signal is cut at the Raspberry Pi end then it will not be pulled down to ground and will be floating - does this matter?

IanSB, 2024-10-19:
@solarmon

At the CPLD end.
The three Pi pins are connected to three of the CPLD programming pins and also connected to three general purpose CPLD pins.

Cutting the jumpers isolates the connection to the three general purpose CPLD pins while leaving the Pi pins connected to the three CPLD programming pins so that the CPLD can still be programmed. If you isolate at the Pi end they won't be connected to anything and you won't be able to program the CPLD.

solarmon, 2024-10-19:
@IanSB

OK - so it's not jumpers for the TDI, TCK and TMS pins on the CPLD pins themselves, but for the other GPIO that it shares connectivity with.

Previously, I had referenced this:

JP1 = GPI00 = TDI
JP2 = GPI020 = TCK
JP4 = GPI01 = TMS

But I now know it should really be for these pins (at least for the XC9572XL PLCC chip that I'm targeting):

JP1 = GPI00 = SPDATA (13)
JP2 = GPI020 = SPCLK (6)
JP4 = GPI01 = CLKEN (12)

Thank you

venice1200, 2024-11-01:
From my point of view we can close the issue, or not?

Closed 2024-11-03.

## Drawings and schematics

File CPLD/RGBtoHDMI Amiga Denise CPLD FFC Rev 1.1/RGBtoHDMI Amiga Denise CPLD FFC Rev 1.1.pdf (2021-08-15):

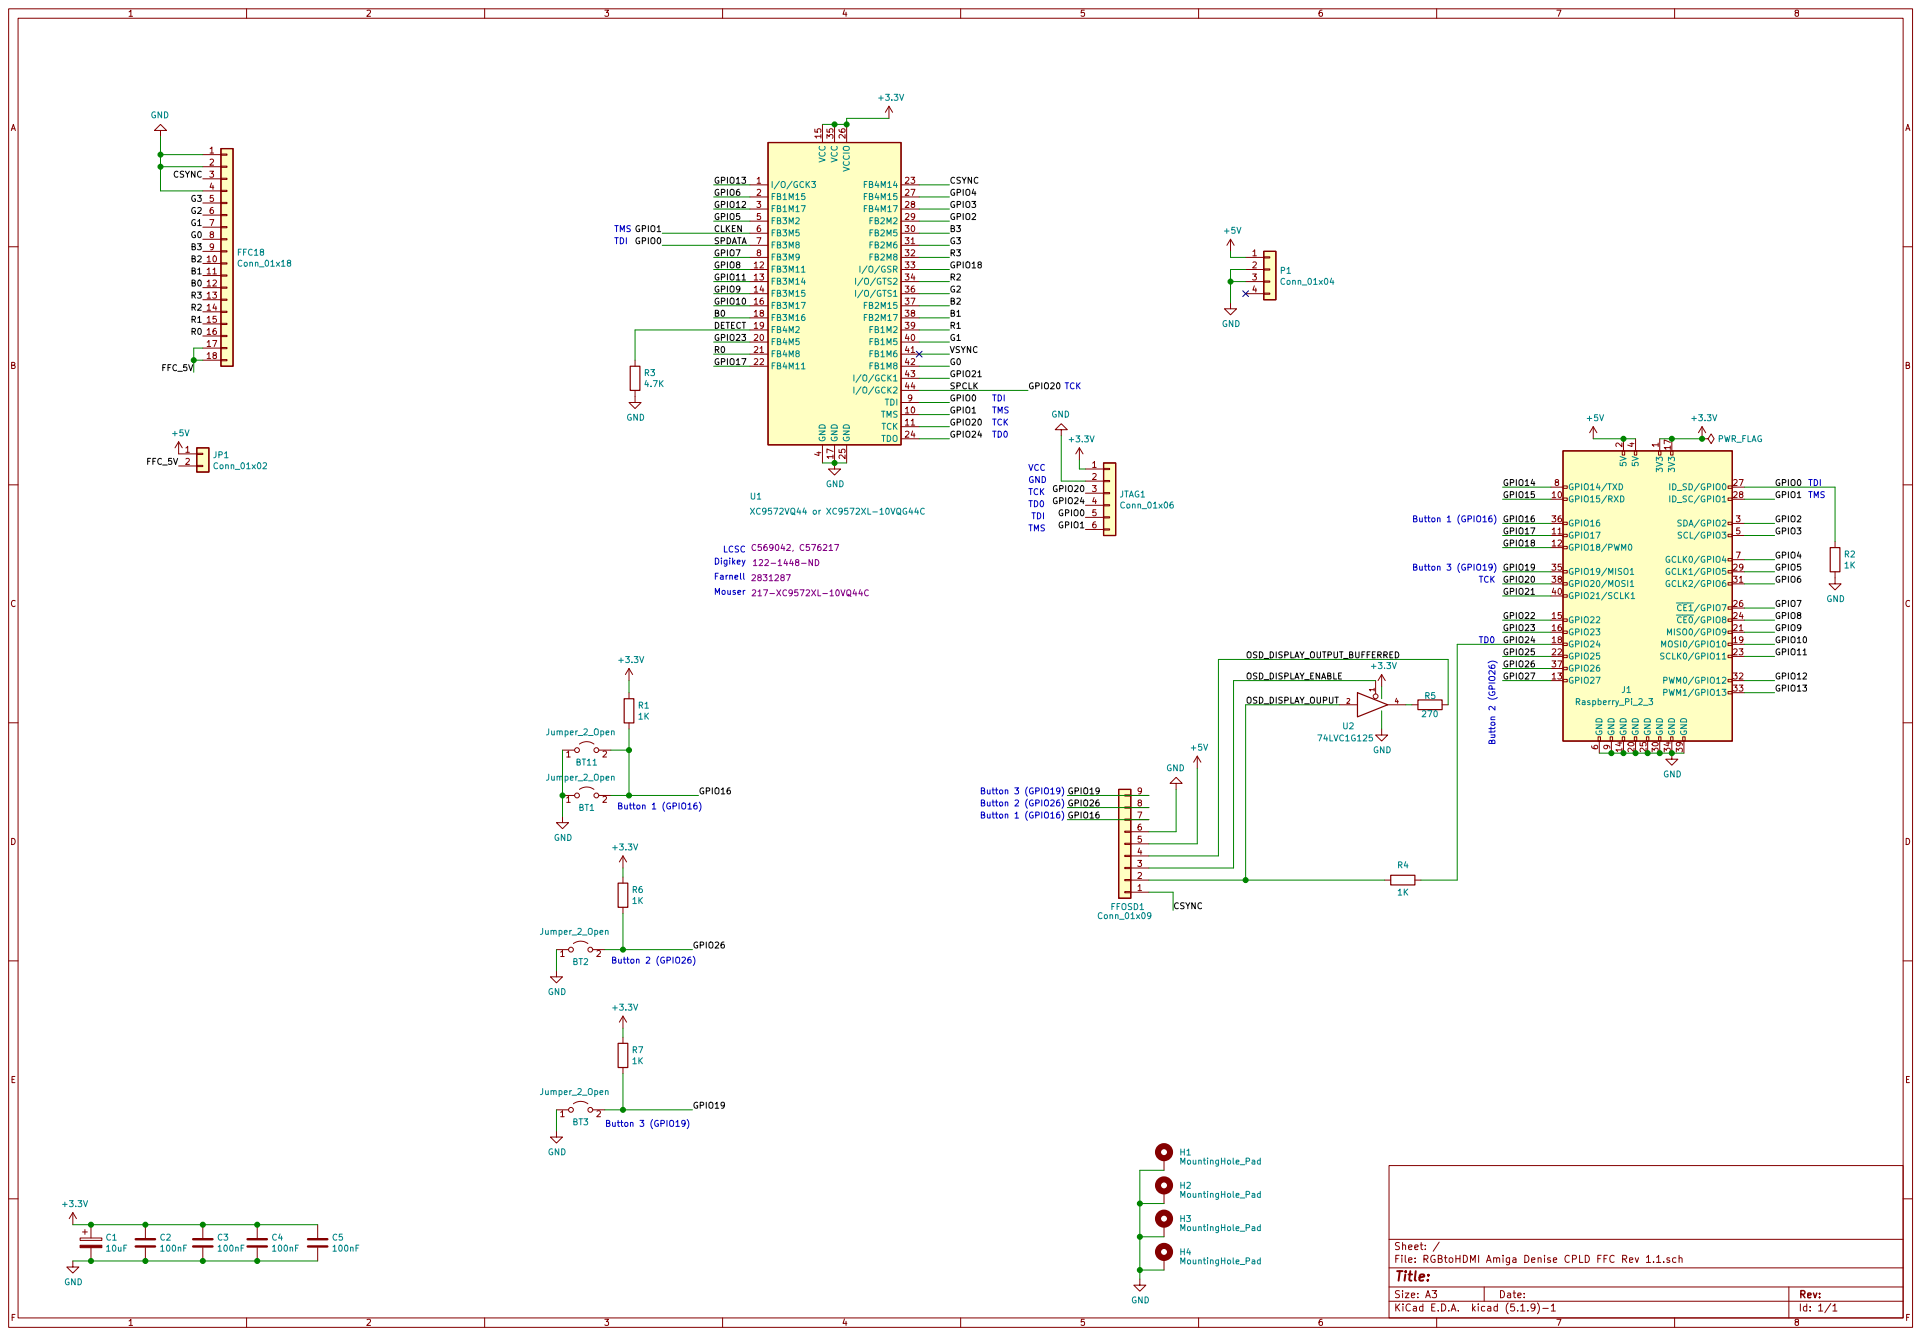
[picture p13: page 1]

LCSC
Button 3 (GPIO19) Farnell Digikey Mouser

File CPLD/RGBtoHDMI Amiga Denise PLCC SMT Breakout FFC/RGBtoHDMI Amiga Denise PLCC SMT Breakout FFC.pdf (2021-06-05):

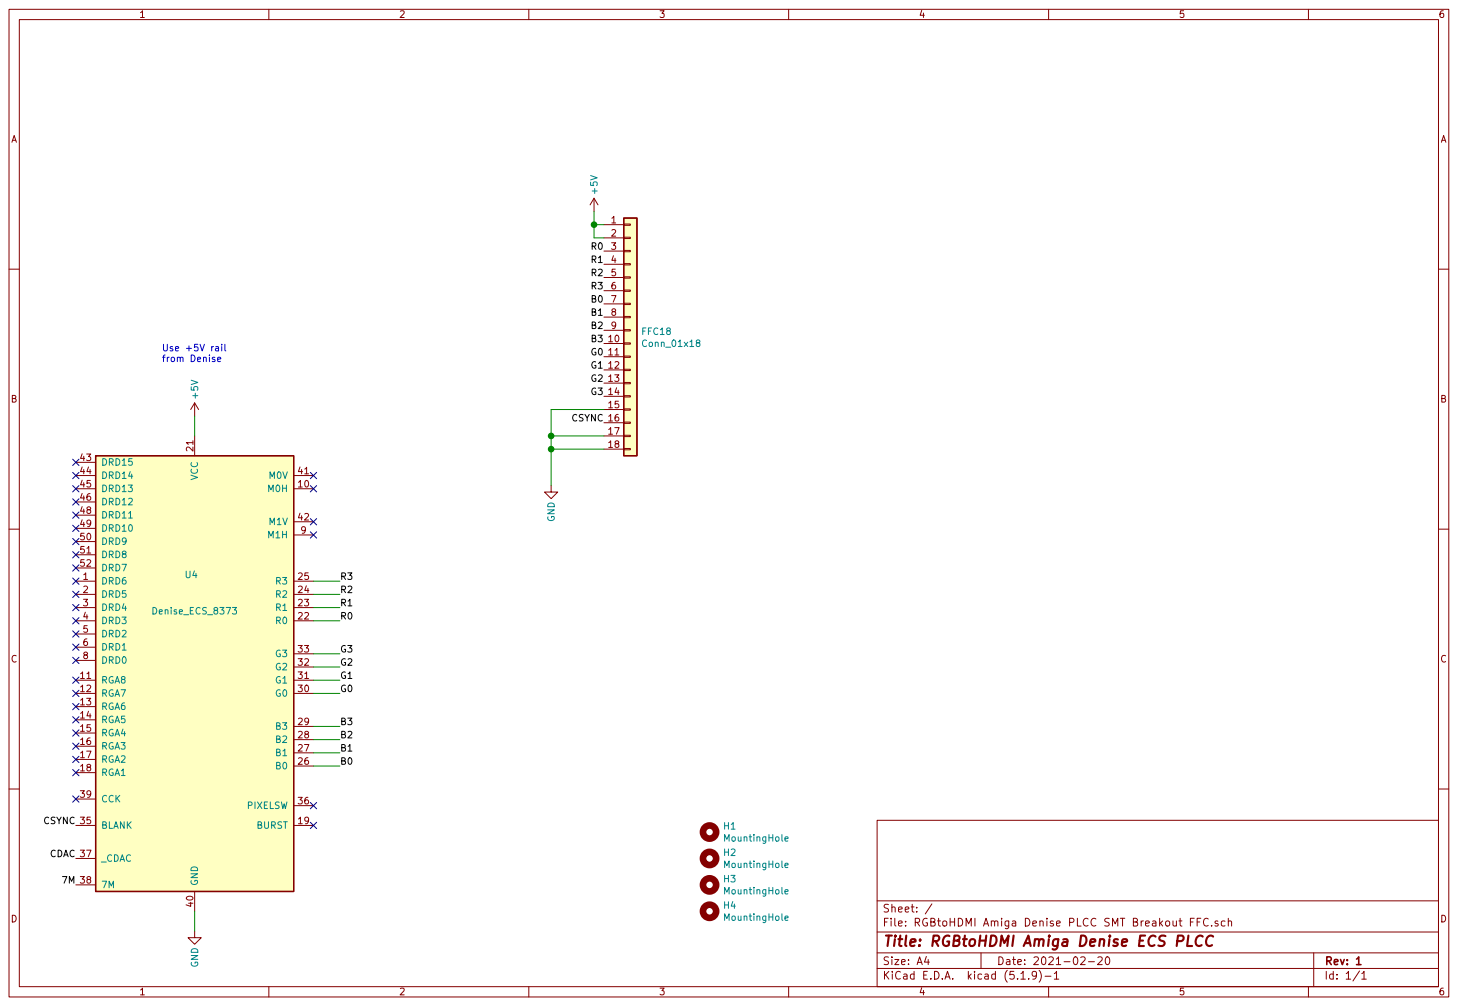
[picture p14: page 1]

B2 Use +5V rail from Denise

Id: 1/1 Title: RGBtoHDMI Amiga Denise ECS PLCC

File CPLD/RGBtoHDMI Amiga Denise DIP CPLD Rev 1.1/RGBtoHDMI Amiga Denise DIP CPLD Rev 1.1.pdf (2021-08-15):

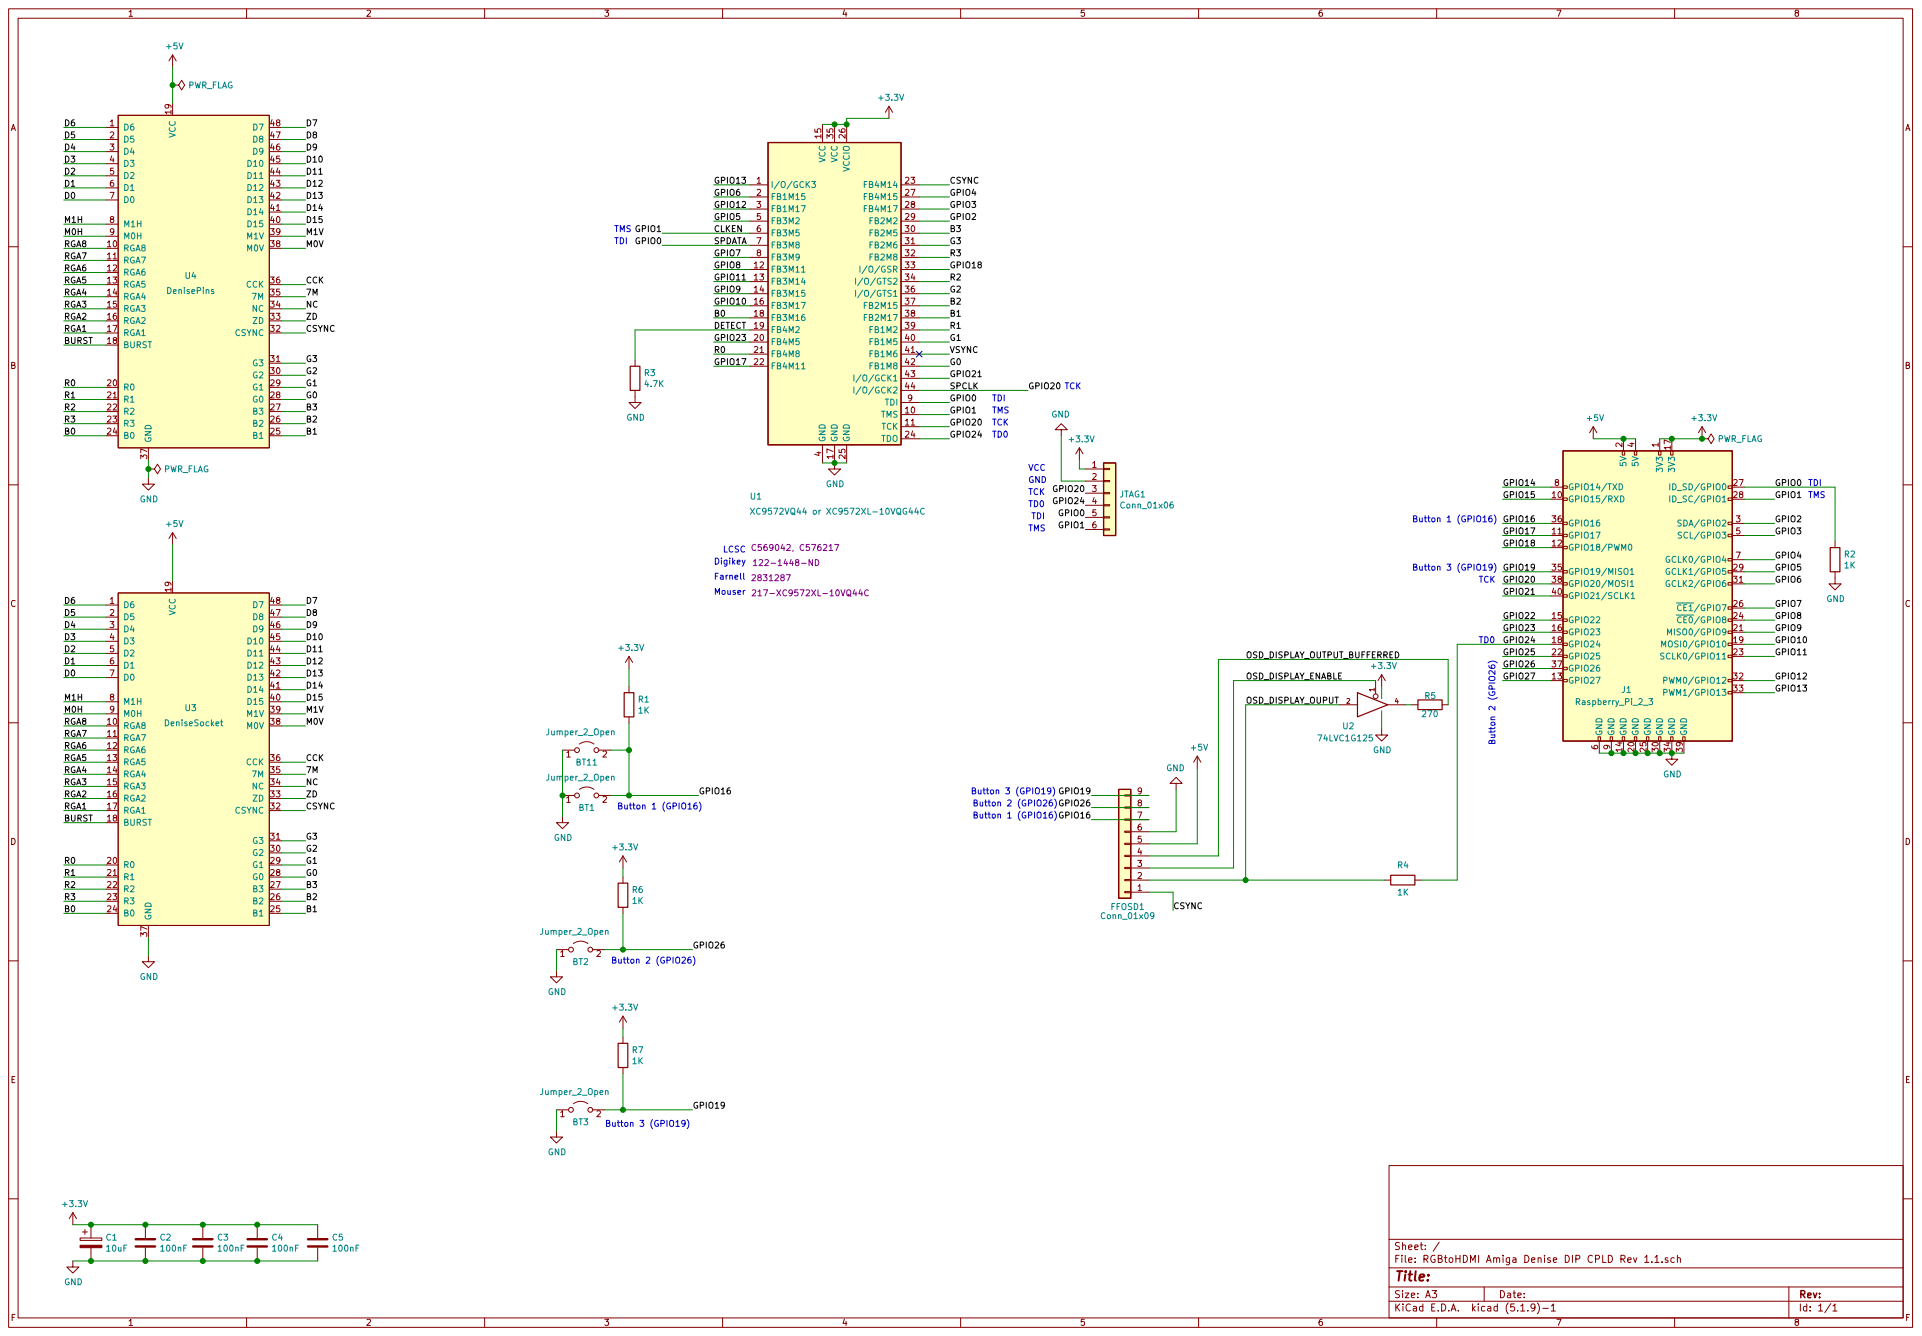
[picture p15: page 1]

File: RGBtoHDMI Amiga Denise DIP CPLD Rev 1.1.sch Sheet: /

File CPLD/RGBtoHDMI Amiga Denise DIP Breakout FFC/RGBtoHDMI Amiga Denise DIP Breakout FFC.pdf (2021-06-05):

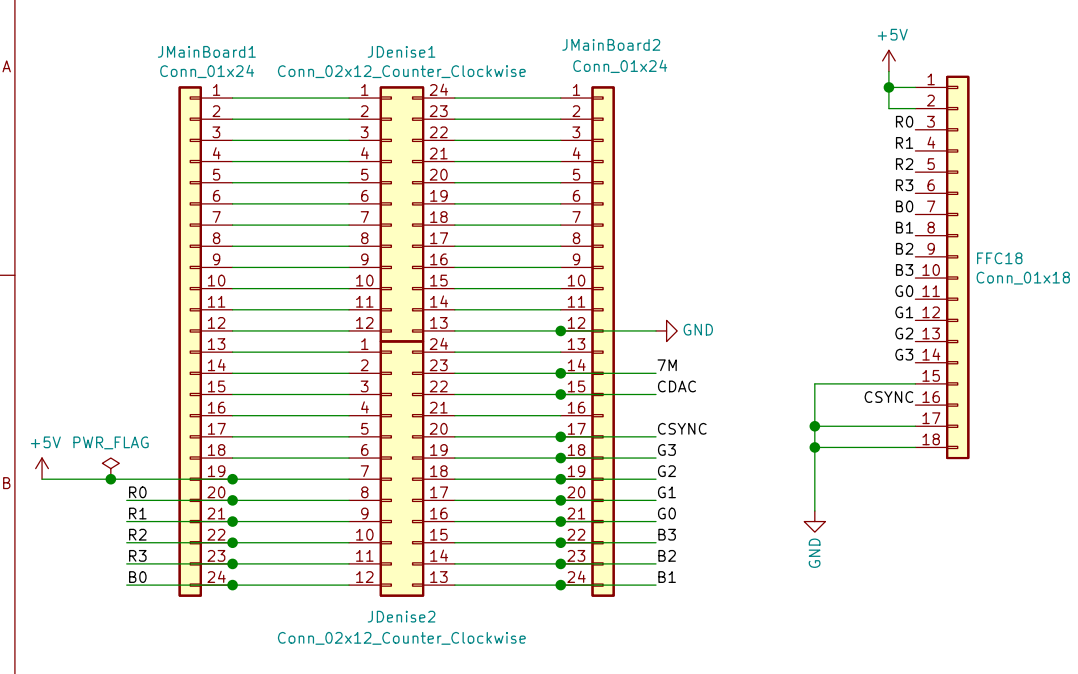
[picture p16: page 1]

2 2 | 23 2
3 3 | 22 3
4 4 | 21 4
5 5 | 20 5
6 6 | 19 6
7 7 | 18 7
8 8 | 17 8
9 9 | 16 9
10 10 | 15 10
11 11 | 14 11
12 12 | 13 12 24 13

File: RGBtoHDMI Amiga Denise DIP Breakout FFC.sch Sheet: /
Id: 1/1 Title: RGBtoHDMI Denise Adapter - v2++ Rev 2 by solarmon

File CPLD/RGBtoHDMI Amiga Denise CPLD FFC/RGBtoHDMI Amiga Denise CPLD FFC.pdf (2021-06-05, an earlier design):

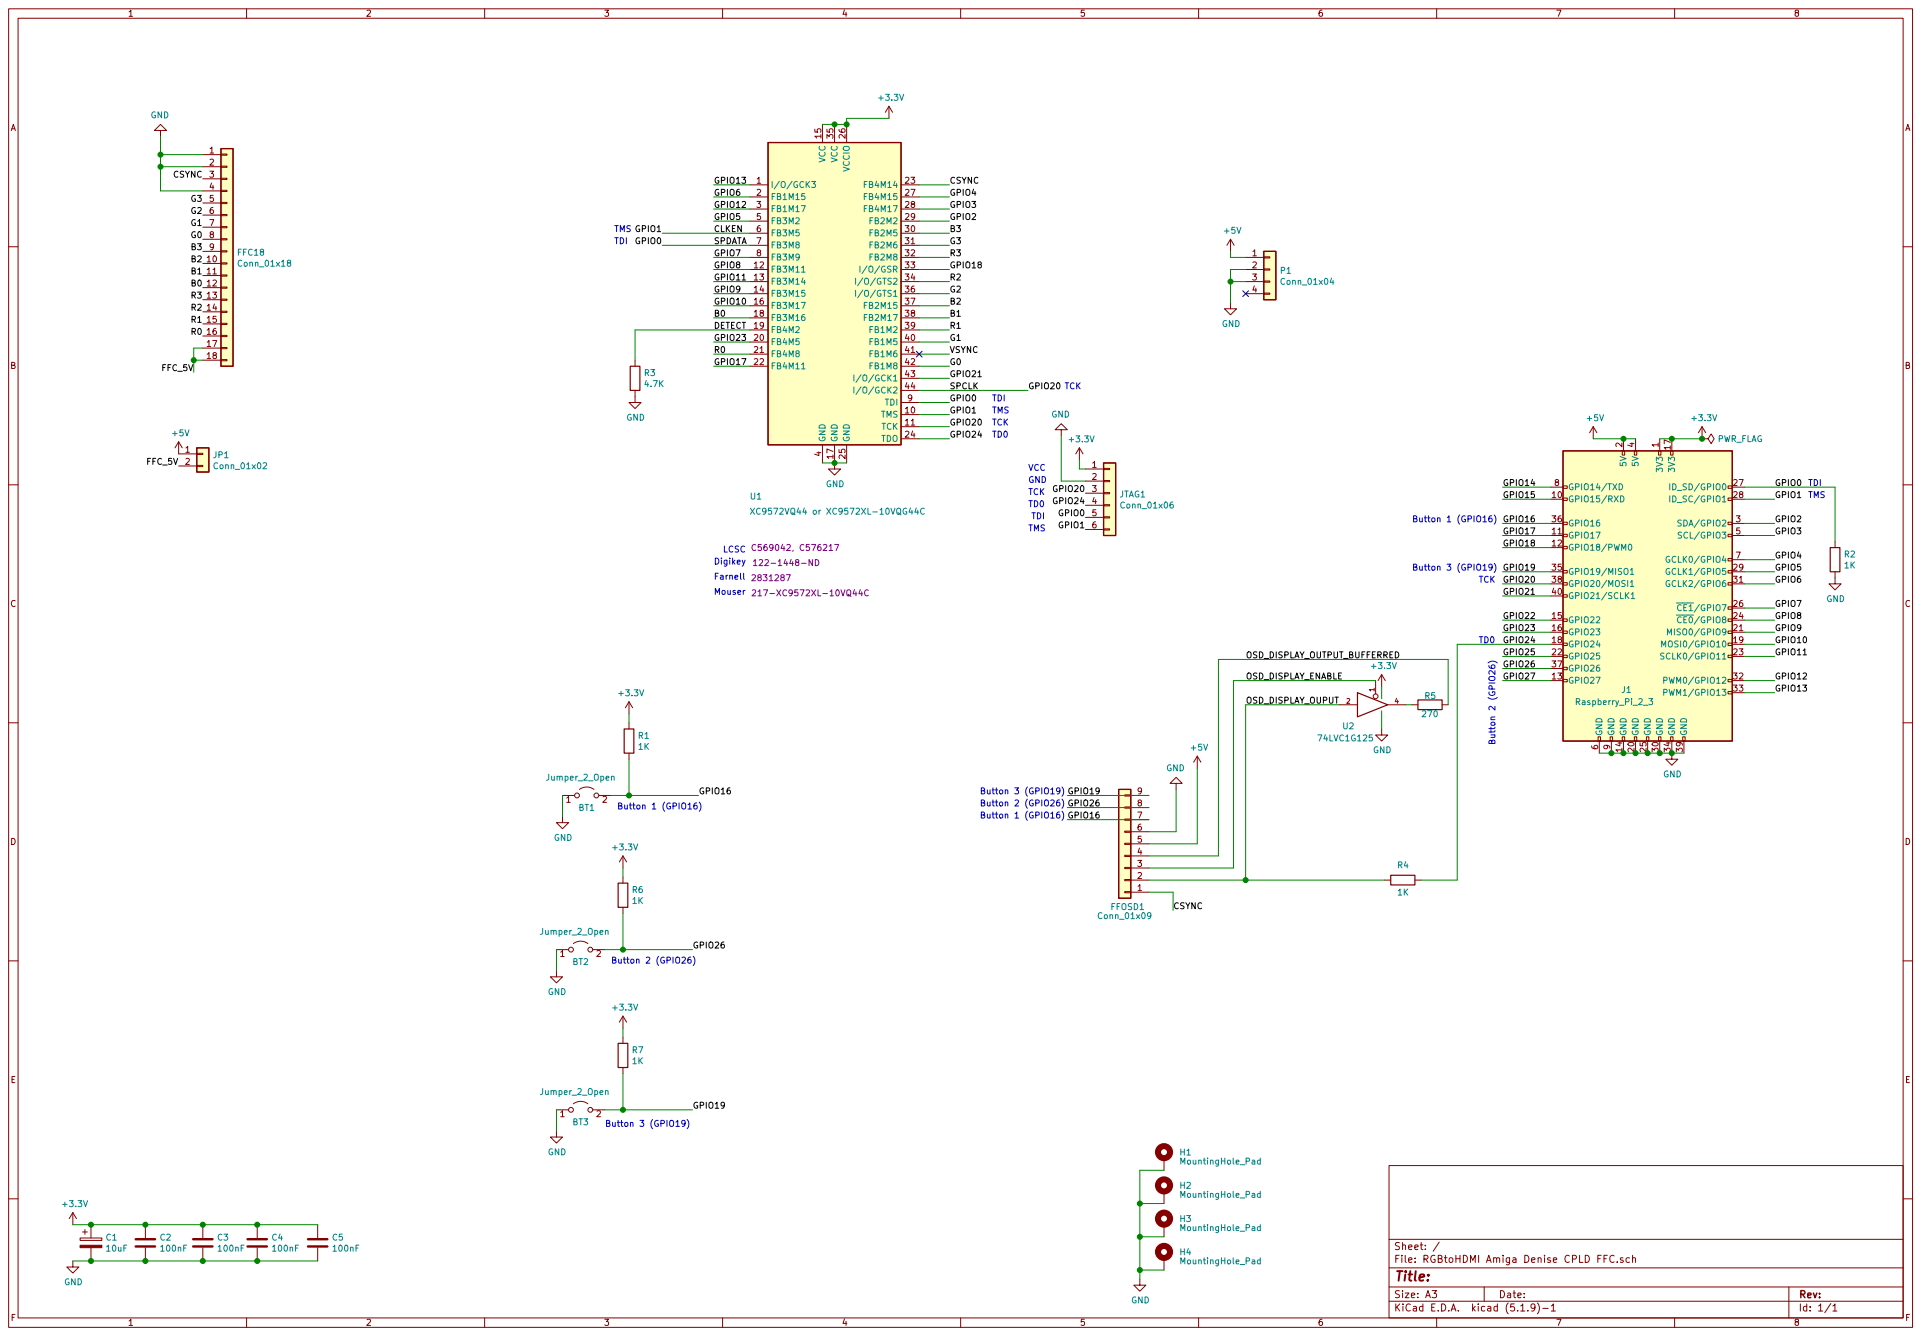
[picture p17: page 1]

File: RGBtoHDMI Amiga Denise CPLD FFC.sch Sheet: / GND

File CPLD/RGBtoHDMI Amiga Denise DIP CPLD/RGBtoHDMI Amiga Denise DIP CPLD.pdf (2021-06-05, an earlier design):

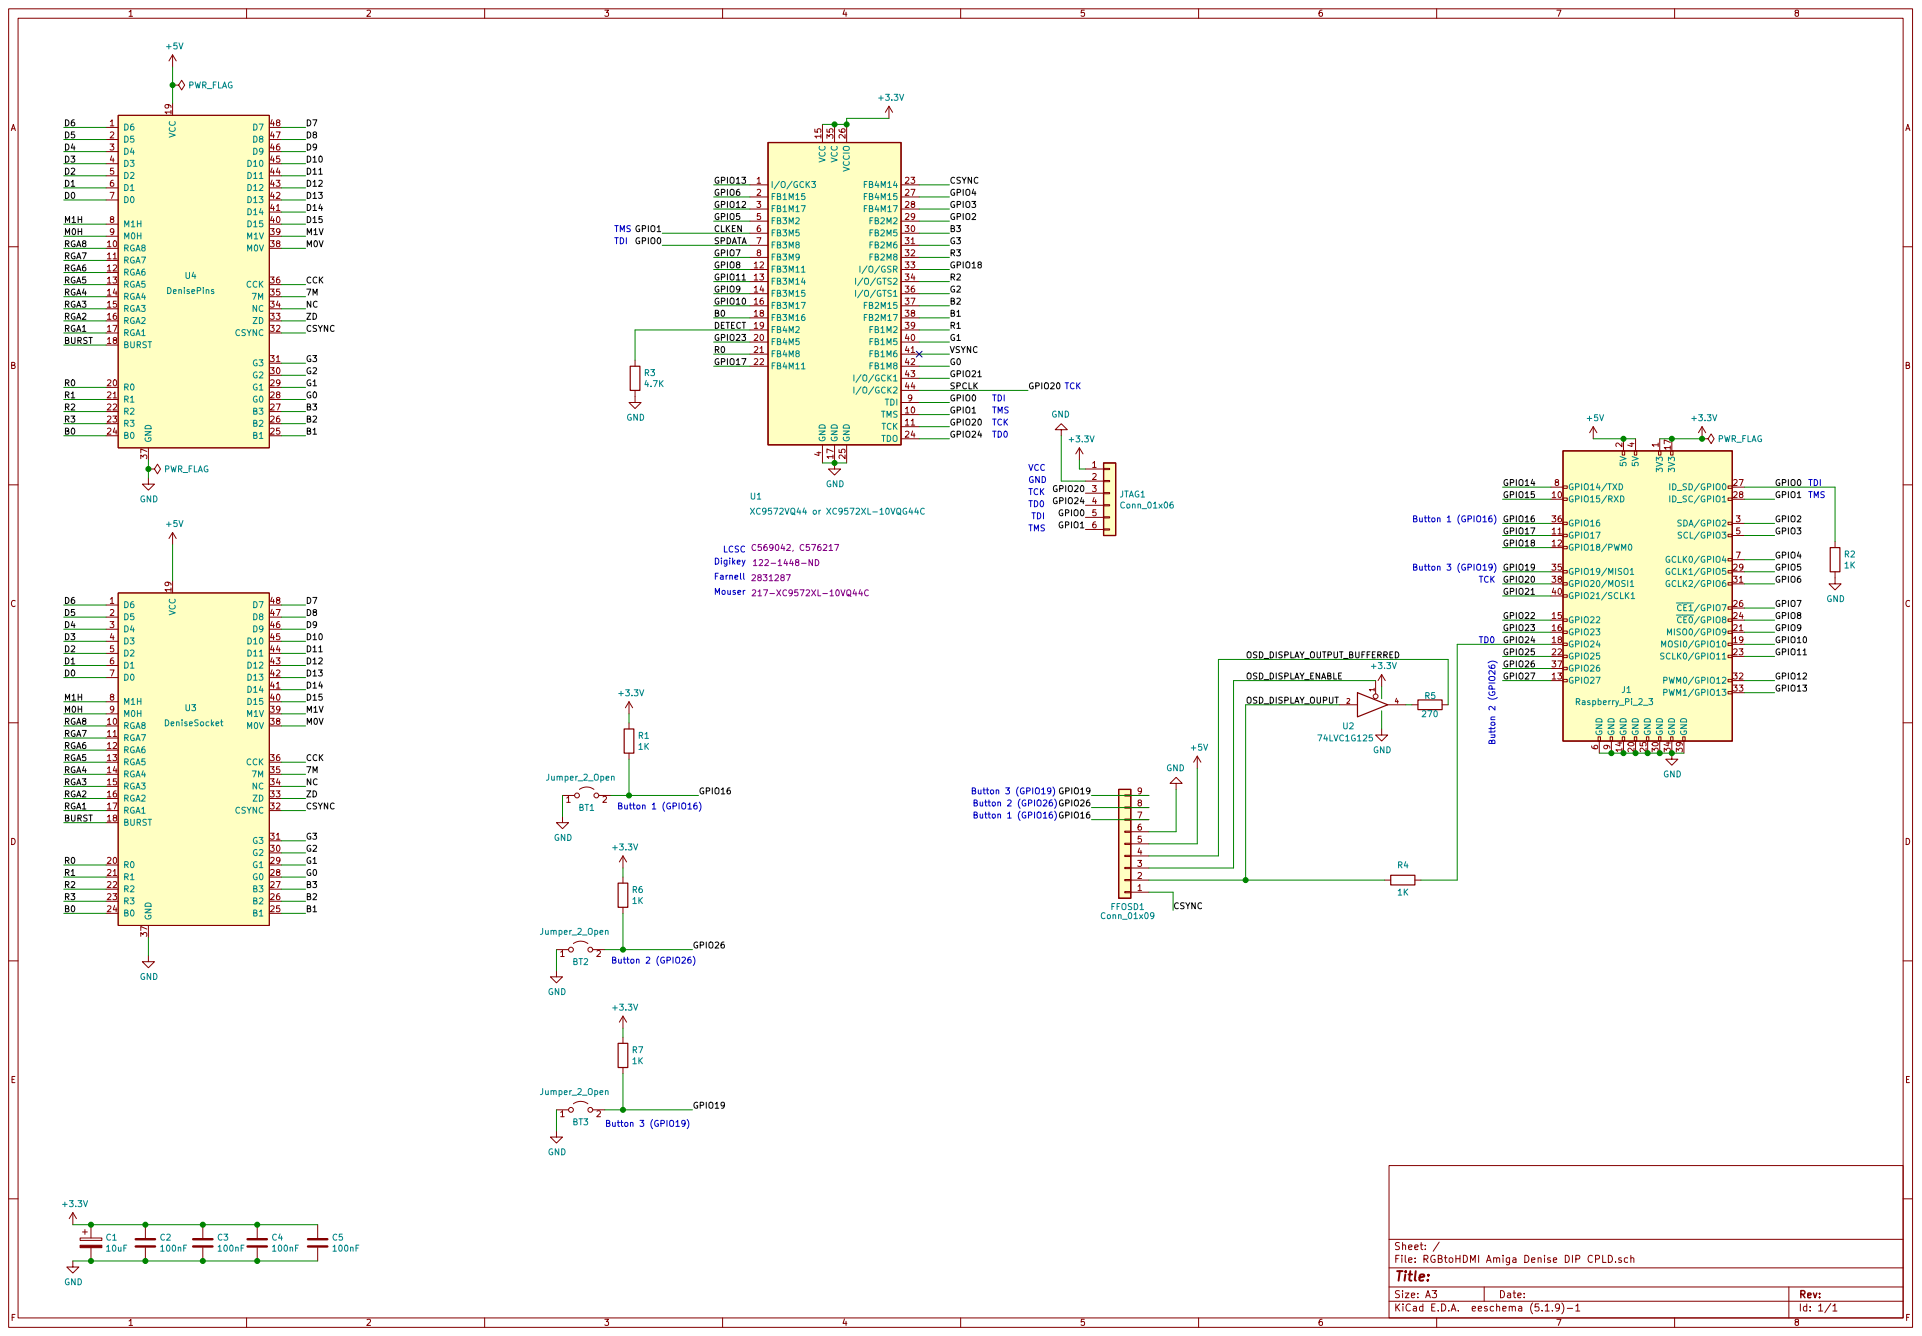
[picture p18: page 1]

File: RGBtoHDMI Amiga Denise DIP CPLD.sch Sheet: / R4

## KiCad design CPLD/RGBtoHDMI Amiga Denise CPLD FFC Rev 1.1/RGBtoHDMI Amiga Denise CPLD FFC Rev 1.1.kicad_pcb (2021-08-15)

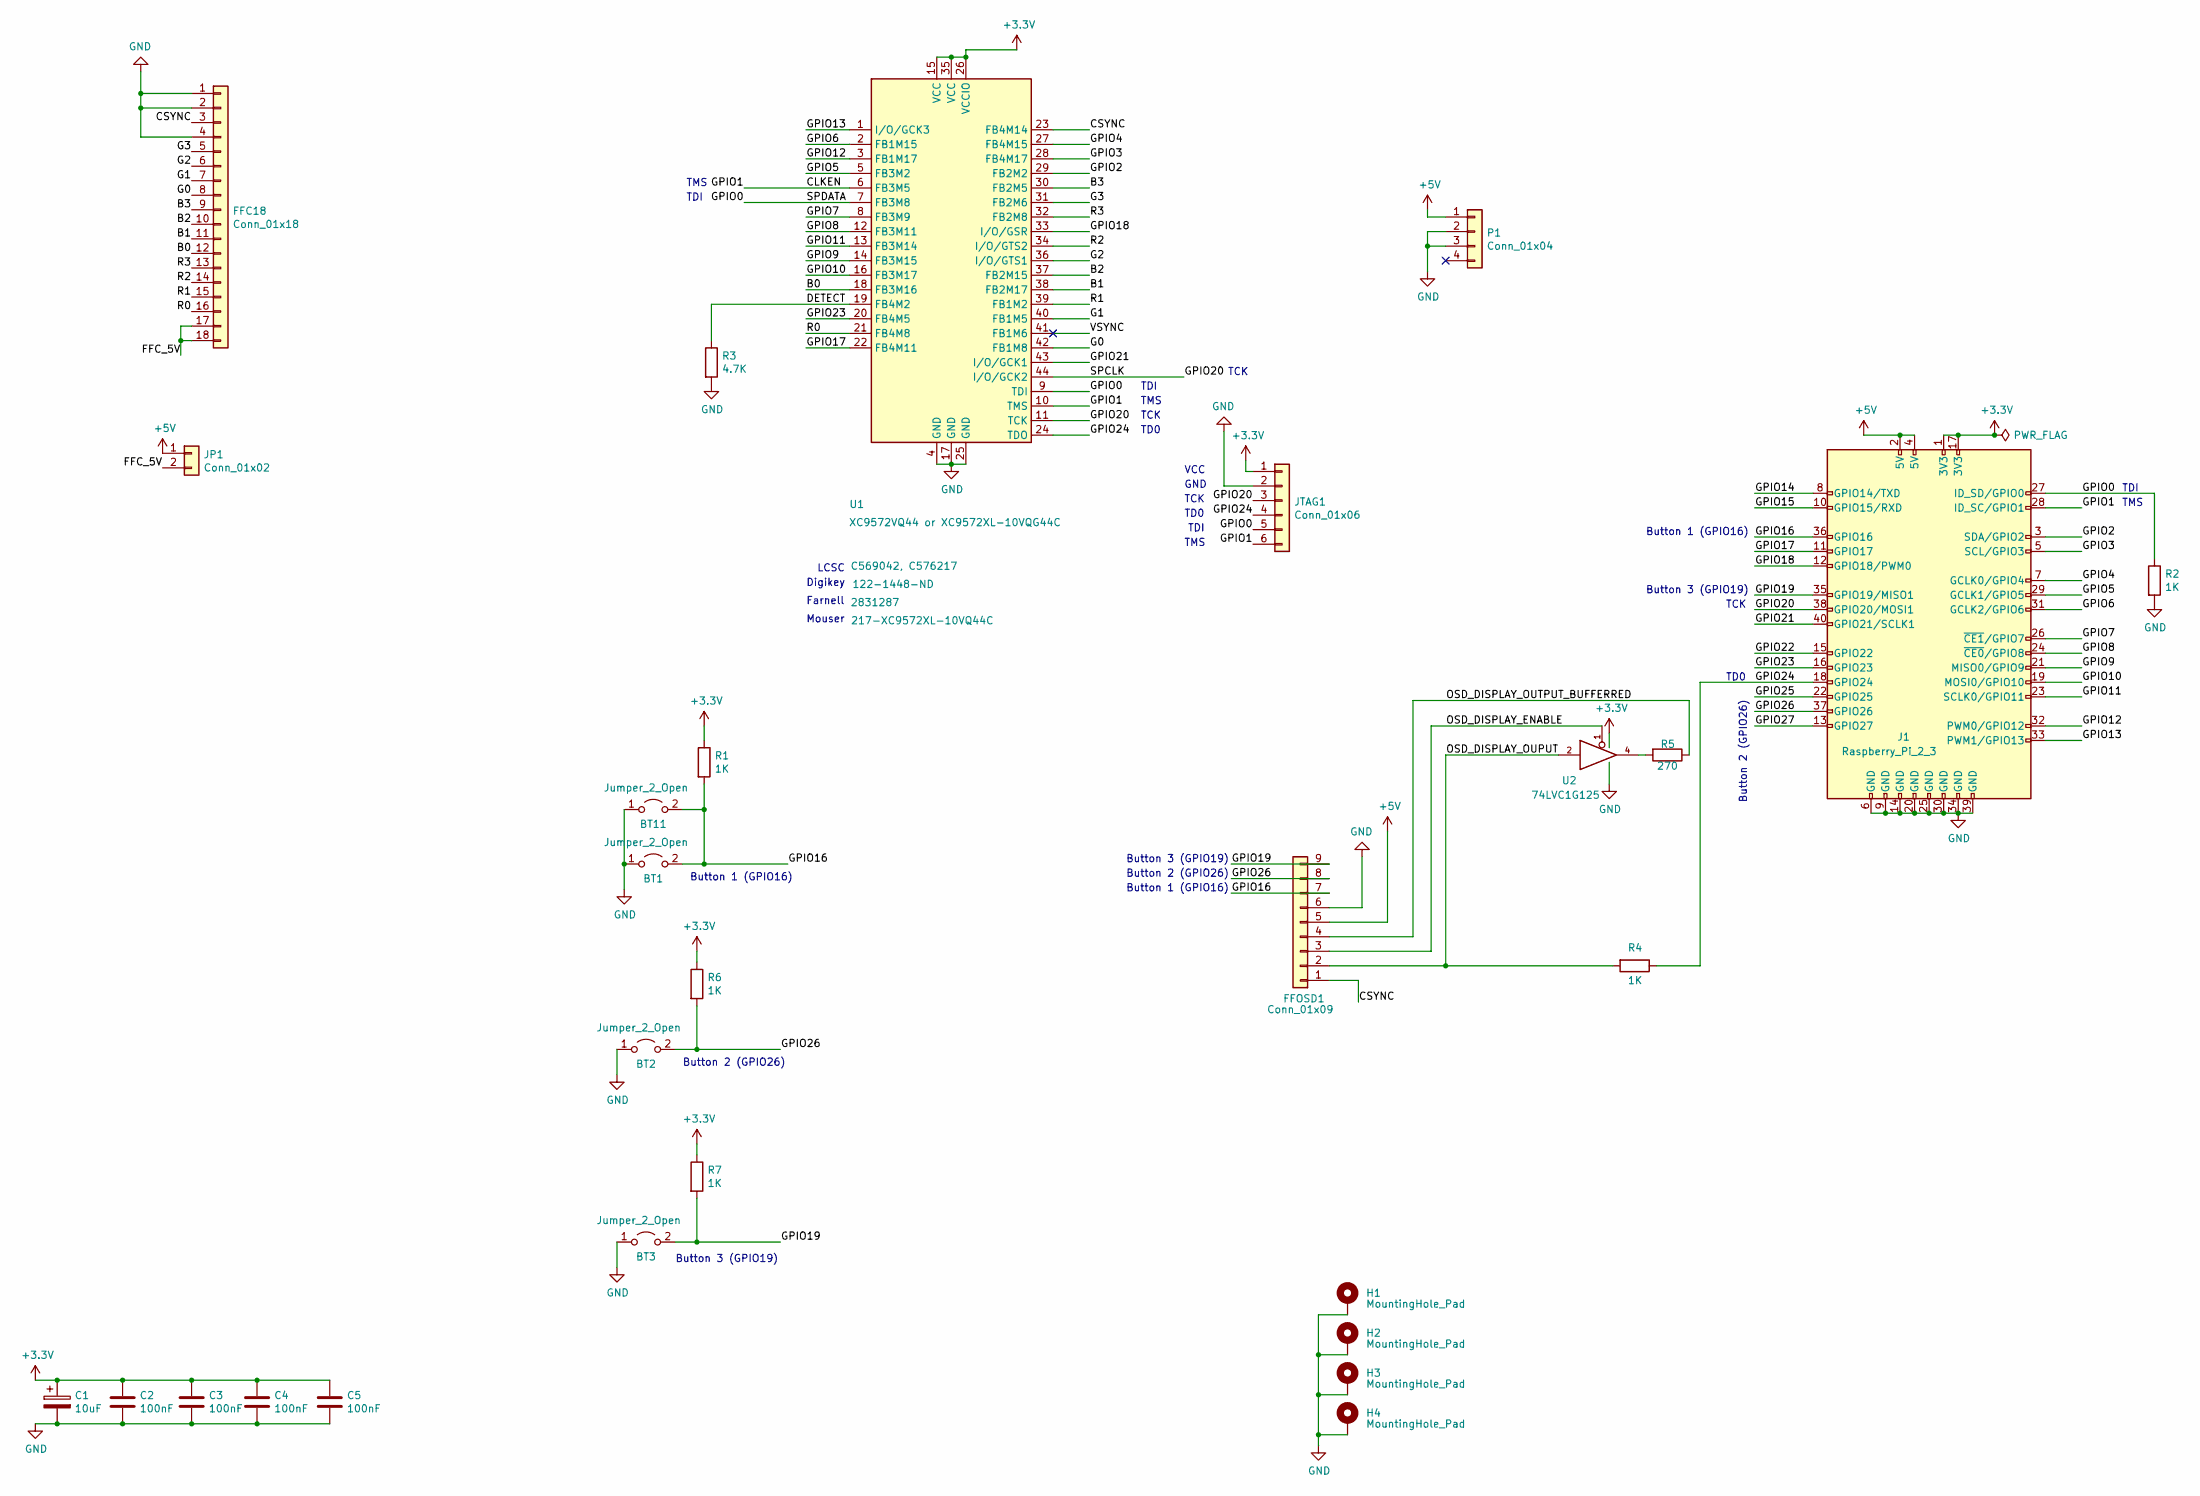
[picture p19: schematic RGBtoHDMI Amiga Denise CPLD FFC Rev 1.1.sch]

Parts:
BT1, BT2, BT3: Jumper_2_Open; PinHeader_1x02_P2.54mm_Horizontal
BT11: Jumper_2_Open; PUSH_BUTTON_RIGHT_ANGLE
C1: 10uF; C_0805_2012Metric_Pad1.18x1.45mm_HandSolder
C2, C3, C4, C5: 100nF; C_0805_2012Metric_Pad1.18x1.45mm_HandSolder
FFC18: Conn_01x18; FPC-SMD_X10B25U18T
FFOSD1: Conn_01x09; PinHeader_1x09_P2.54mm_Horizontal
H1, H2, H3, H4: MountingHole_Pad; MountingHole_3.2mm_M3_Pad_Via
J1: Raspberry_Pi_2_3; PinSocket_2x20_P2.54mm_Vertical
JP1: Conn_01x02; PinHeader_1x02_P2.54mm_Horizontal
JTAG1: Conn_01x06; PinHeader_1x06_P2.54mm_Vertical
P1: Conn_01x04; PinHeader_1x04_P2.54mm_Horizontal
R1, R2, R4, R6, R7: 1K; R_0805_2012Metric_Pad1.20x1.40mm_HandSolder
R3: 4.7K; R_0805_2012Metric_Pad1.20x1.40mm_HandSolder
R5: 270; R_0805_2012Metric_Pad1.20x1.40mm_HandSolder
U1: XC9572VQ44 or XC9572XL-10VQG44C; TQFP-44_10x10mm_P0.8mm; LCSC C569042, C576217
U2: 74LVC1G125; SOT-753

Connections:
+3V3: C1.1, C2.1, C3.1, C4.1, C5.1, J1.1 (3V3), J1.17 (3V3), JTAG1.1, R1.1, R6.1, R7.1, U1.15 (VCC), U1.26 (VCCIO), U1.35 (VCC), U2.5 (VCC)
+5V: FFOSD1.5, J1.2 (5V), J1.4 (5V), JP1.1, P1.1
/B0: FFC18.12, U1.18 (FB3M16)
/B1: FFC18.11, U1.38 (FB2M17)
/B2: FFC18.10, U1.37 (FB2M15)
/B3: FFC18.9, U1.30 (FB2M5)
/CLKEN: J1.28 (ID_SC/GPIO1), JTAG1.6, U1.6 (FB3M5), U1.10 (TMS)
/CSYNC: FFC18.3, FFOSD1.1, U1.23 (FB4M14)
/DETECT: R3.1, U1.19 (FB4M2)
/FFC_5V: FFC18.17, FFC18.18, JP1.2
/G0: FFC18.8, U1.42 (FB1M8)
/G1: FFC18.7, U1.40 (FB1M5)
/G2: FFC18.6, U1.36 (I/O/GTS1)
/G3: FFC18.5, U1.31 (FB2M6)
/GPIO0: J1.27 (ID_SD/GPIO0), JTAG1.5, R2.1, U1.7 (FB3M8), U1.9 (TDI)
/GPIO2: J1.3 (SDA/GPIO2), U1.29 (FB2M2)
/GPIO3: J1.5 (SCL/GPIO3), U1.28 (FB4M17)
/GPIO4: J1.7 (GCLK0/GPIO4), U1.27 (FB4M15)
/GPIO5: J1.29 (GCLK1/GPIO5), U1.5 (FB3M2)
/GPIO6: J1.31 (GCLK2/GPIO6), U1.2 (FB1M15)
/GPIO7: J1.26 (~CE1~/GPIO7), U1.8 (FB3M9)
/GPIO8: J1.24 (~CE0~/GPIO8), U1.12 (FB3M11)
/GPIO9: J1.21 (MISO0/GPIO9), U1.14 (FB3M15)
/GPIO10: J1.19 (MOSI0/GPIO10), U1.16 (FB3M17)
/GPIO11: J1.23 (SCLK0/GPIO11), U1.13 (FB3M14)
/GPIO12: J1.32 (PWM0/GPIO12), U1.3 (FB1M17)
/GPIO13: J1.33 (PWM1/GPIO13), U1.1 (I/O/GCK3)
/GPIO14: J1.8 (GPIO14/TXD)
/GPIO15: J1.10 (GPIO15/RXD)
/GPIO16: BT1.2 (B), BT11.2 (B), FFOSD1.7, J1.36 (GPIO16), R1.2
/GPIO17: J1.11 (GPIO17), U1.22 (FB4M11)
/GPIO18: J1.12 (GPIO18/PWM0), U1.33 (I/O/GSR)
/GPIO19: BT3.2 (B), FFOSD1.9, J1.35 (GPIO19/MISO1), R7.2
/GPIO20: J1.38 (GPIO20/MOSI1), JTAG1.3, U1.11 (TCK), U1.44 (I/O/GCK2)
/GPIO21: J1.40 (GPIO21/SCLK1), U1.43 (I/O/GCK1)
/GPIO22: J1.15 (GPIO22)
/GPIO23: J1.16 (GPIO23), U1.20 (FB4M5)
/GPIO24: J1.18 (GPIO24), JTAG1.4, R4.1, U1.24 (TDO)
/GPIO25: J1.22 (GPIO25)
/GPIO26: BT2.2 (B), FFOSD1.8, J1.37 (GPIO26), R6.2
/GPIO27: J1.13 (GPIO27)
/OSD_DISPLAY_ENABLE: FFOSD1.3, U2.1
/OSD_DISPLAY_OUPUT: FFOSD1.2, R4.2, U2.2
/OSD_DISPLAY_OUTPUT_BUFFERRED: FFOSD1.4, R5.1
/R0: FFC18.16, U1.21 (FB4M8)
/R1: FFC18.15, U1.39 (FB1M2)
/R2: FFC18.14, U1.34 (I/O/GTS2)
/R3: FFC18.13, U1.32 (FB2M8)
/VSYNC: U1.41 (FB1M6)
GND: BT1.1 (A), BT2.1 (A), BT3.1 (A), BT11.1 (A), C1.2, C2.2, C3.2, C4.2, C5.2, FFC18.1, FFC18.2, FFC18.4, FFOSD1.6, H1.1, H2.1, H3.1, H4.1, J1.6 (GND), J1.9 (GND), J1.14 (GND), J1.20 (GND), J1.25 (GND), J1.30 (GND), J1.34 (GND), J1.39 (GND), JTAG1.2, P1.2, P1.3, R2.2, R3.2, U1.4 (GND), U1.17 (GND), U1.25 (GND), U2.3 (GND)
unnamed: R5.2, U2.4

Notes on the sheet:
TD0
TCK
TMS
TDI
GND
VCC
Button 1 (GPIO16)
Button 2 (GPIO26)
Button 3 (GPIO19)
Farnell
Digikey
LCSC
Mouser

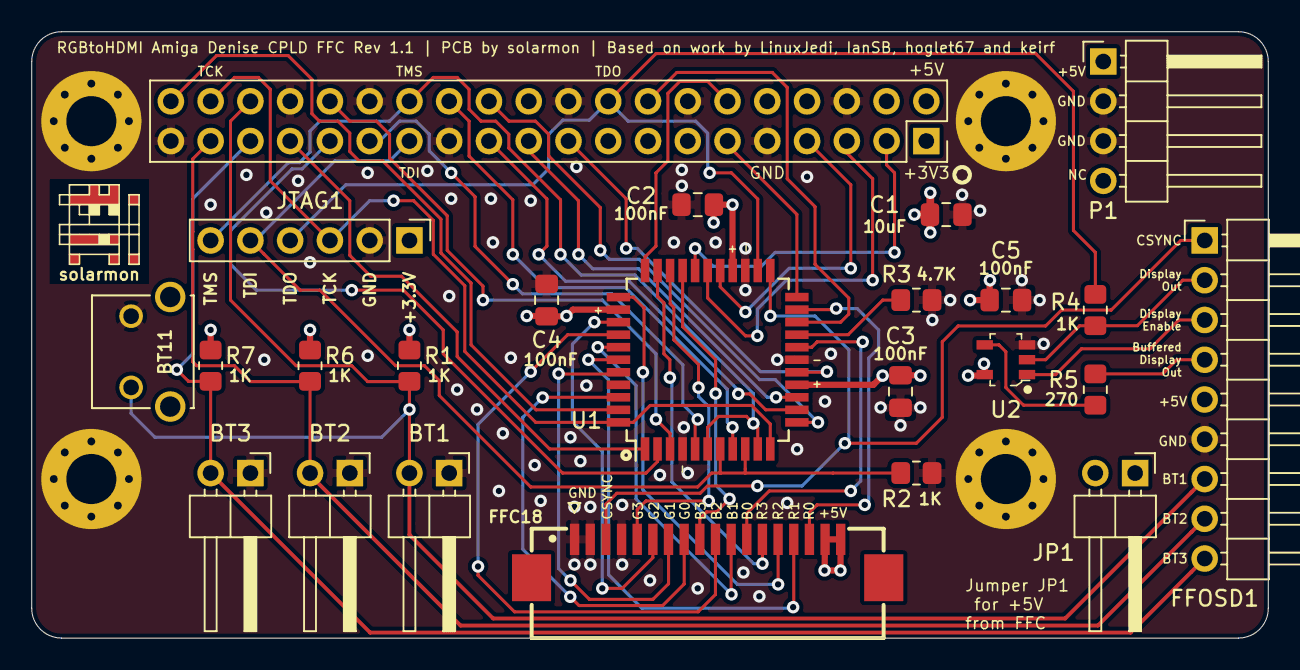
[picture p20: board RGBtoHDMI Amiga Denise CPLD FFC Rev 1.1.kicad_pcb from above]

Board: 2 copper layers, 79.0 x 38.7 mm, 29 parts (0 on the bottom side), 45 nets.

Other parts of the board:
solarmon: solarmon-logo-25mils

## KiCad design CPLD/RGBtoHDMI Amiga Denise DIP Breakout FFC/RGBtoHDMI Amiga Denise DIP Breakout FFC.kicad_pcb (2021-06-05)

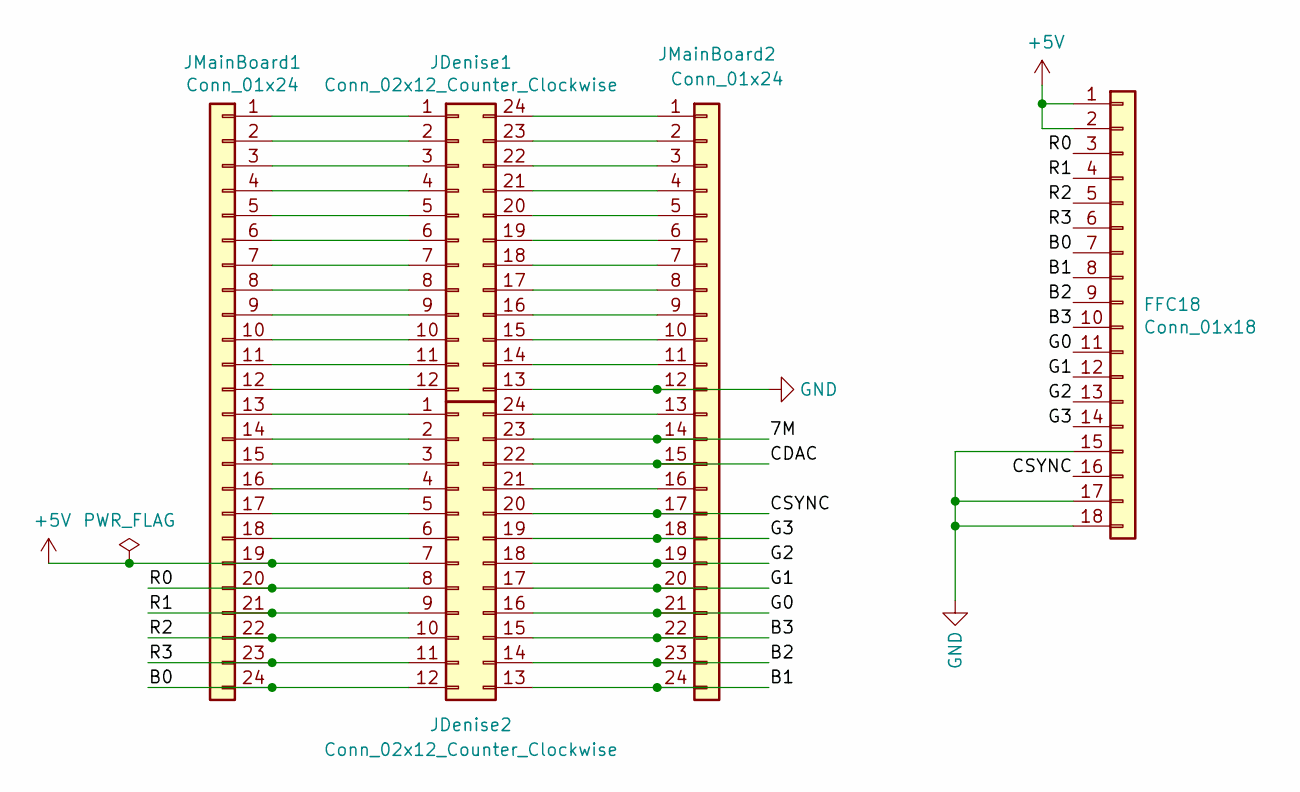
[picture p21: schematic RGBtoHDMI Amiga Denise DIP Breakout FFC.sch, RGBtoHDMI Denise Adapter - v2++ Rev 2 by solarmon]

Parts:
FFC18: Conn_01x18; FPC-SMD_X10B25U18T
JDenise1, JDenise2: Conn_02x12_Counter_Clockwise; DIP-24_W15.24mm_Socket
JMainBoard1, JMainBoard2: Conn_01x24; PinHeader_1x24_P2.54mm_Vertical_smaller

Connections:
+5V: FFC18.1, FFC18.2, JDenise2.7, JMainBoard1.19
/7M: JDenise2.23, JMainBoard2.14
/B0: FFC18.7, JDenise2.12, JMainBoard1.24
/B1: FFC18.8, JDenise2.13, JMainBoard2.24
/B2: FFC18.9, JDenise2.14, JMainBoard2.23
/B3: FFC18.10, JDenise2.15, JMainBoard2.22
/CDAC: JDenise2.22, JMainBoard2.15
/CSYNC: FFC18.16, JDenise2.20, JMainBoard2.17
/G0: FFC18.11, JDenise2.16, JMainBoard2.21
/G1: FFC18.12, JDenise2.17, JMainBoard2.20
/G2: FFC18.13, JDenise2.18, JMainBoard2.19
/G3: FFC18.14, JDenise2.19, JMainBoard2.18
/R0: FFC18.3, JDenise2.8, JMainBoard1.20
/R1: FFC18.4, JDenise2.9, JMainBoard1.21
/R2: FFC18.5, JDenise2.10, JMainBoard1.22
/R3: FFC18.6, JDenise2.11, JMainBoard1.23
GND: FFC18.15, FFC18.17, FFC18.18, FFC18.MP, JDenise1.13, JMainBoard2.12
unnamed: JDenise1.1, JMainBoard1.1
unnamed: JDenise1.2, JMainBoard1.2
unnamed: JDenise1.3, JMainBoard1.3
unnamed: JDenise1.4, JMainBoard1.4
unnamed: JDenise1.5, JMainBoard1.5
unnamed: JDenise1.6, JMainBoard1.6
unnamed: JDenise1.7, JMainBoard1.7
unnamed: JDenise1.8, JMainBoard1.8
unnamed: JDenise1.9, JMainBoard1.9
unnamed: JDenise1.10, JMainBoard1.10
unnamed: JDenise1.11, JMainBoard1.11
unnamed: JDenise1.12, JMainBoard1.12
unnamed: JDenise1.14, JMainBoard2.11
unnamed: JDenise1.15, JMainBoard2.10
unnamed: JDenise1.16, JMainBoard2.9
unnamed: JDenise1.17, JMainBoard2.8
unnamed: JDenise1.18, JMainBoard2.7
unnamed: JDenise1.19, JMainBoard2.6
unnamed: JDenise1.20, JMainBoard2.5
unnamed: JDenise1.21, JMainBoard2.4
unnamed: JDenise1.22, JMainBoard2.3
unnamed: JDenise1.23, JMainBoard2.2
unnamed: JDenise1.24, JMainBoard2.1
unnamed: JDenise2.1, JMainBoard1.13
unnamed: JDenise2.2, JMainBoard1.14
unnamed: JDenise2.3, JMainBoard1.15
unnamed: JDenise2.4, JMainBoard1.16
unnamed: JDenise2.5, JMainBoard1.17
unnamed: JDenise2.6, JMainBoard1.18
unnamed: JDenise2.21, JMainBoard2.16
unnamed: JDenise2.24, JMainBoard2.13

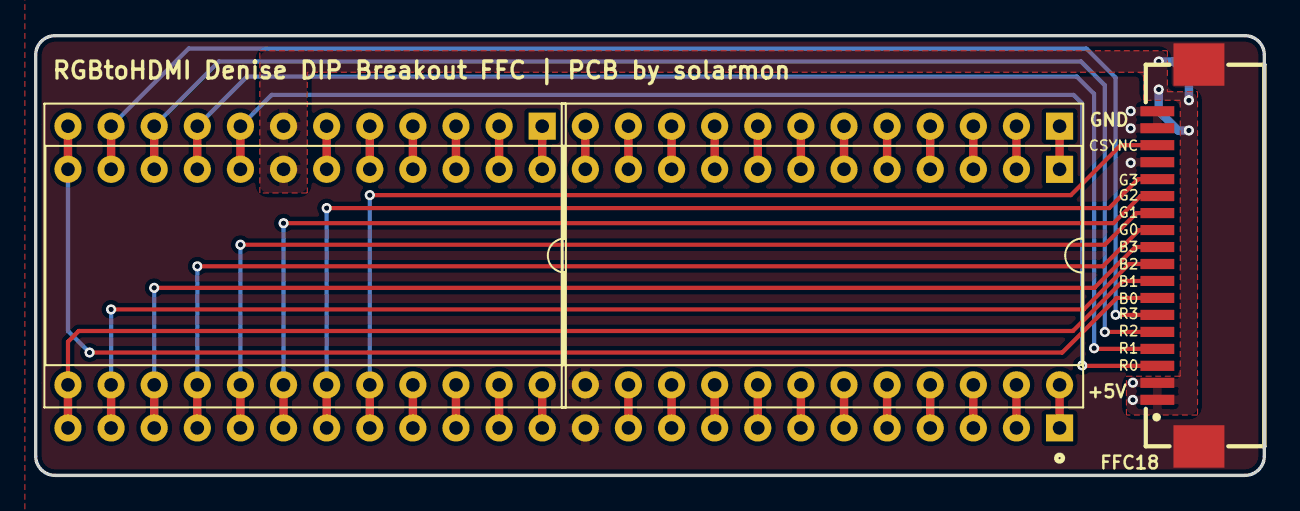
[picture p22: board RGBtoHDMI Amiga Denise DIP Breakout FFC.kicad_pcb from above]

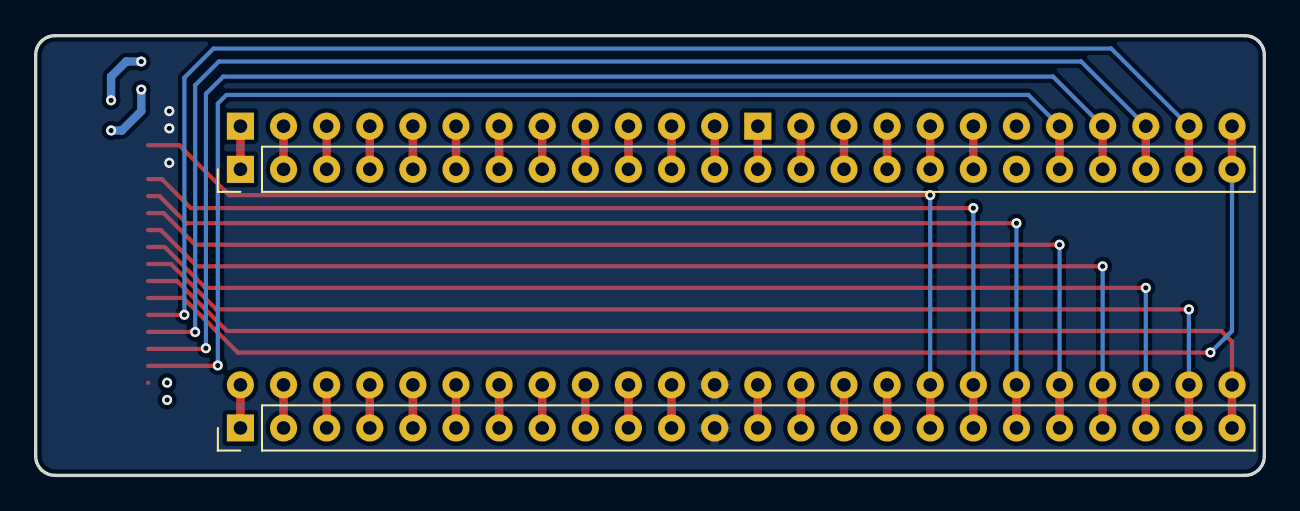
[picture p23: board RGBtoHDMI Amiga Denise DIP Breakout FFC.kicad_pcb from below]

Board: 2 copper layers, 72.4 x 25.9 mm, 5 parts (2 on the bottom side), 48 nets.

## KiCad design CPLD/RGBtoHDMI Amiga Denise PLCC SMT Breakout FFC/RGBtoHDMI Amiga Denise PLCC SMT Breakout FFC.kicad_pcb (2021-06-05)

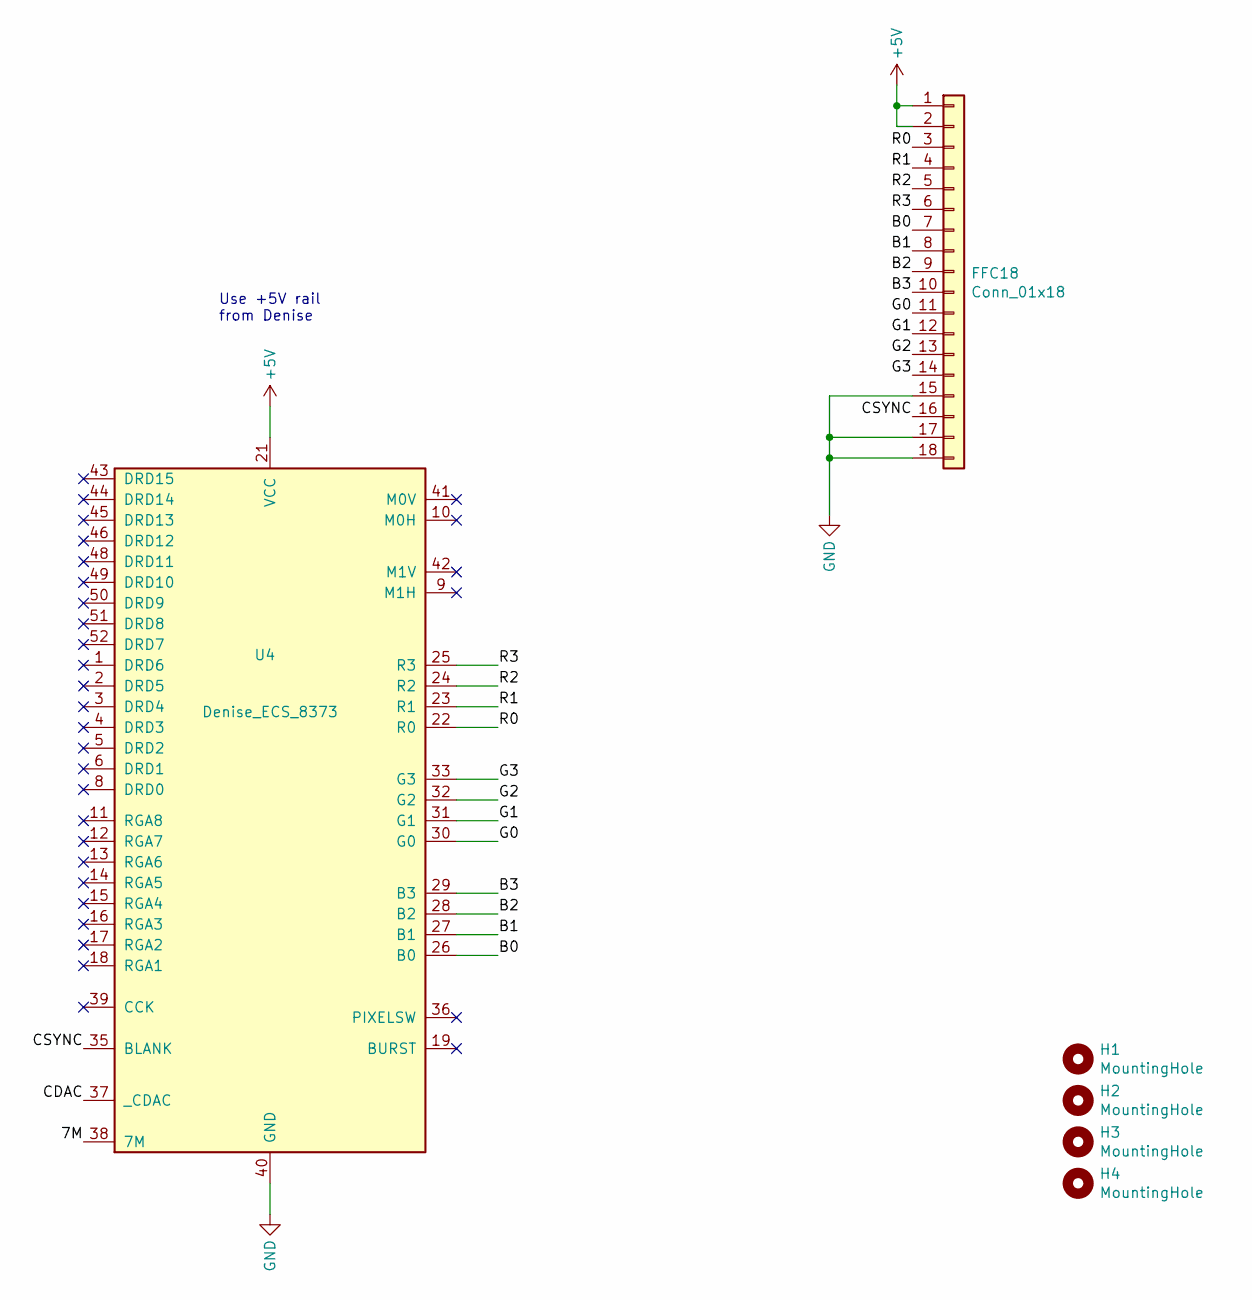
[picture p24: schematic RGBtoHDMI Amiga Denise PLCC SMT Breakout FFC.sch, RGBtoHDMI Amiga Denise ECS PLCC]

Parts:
FFC18: Conn_01x18; FPC-SMD_X10B25U18T
H1, H2, H3, H4: MountingHole; MountingHole_4.3mm_M4
U4: Denise_ECS_8373; PLCC-52_SMD-Socket_Reversed_Hat

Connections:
+5V: FFC18.1, FFC18.2, U4.21 (VCC)
/7M: U4.38 (7M)
/B0: FFC18.7, U4.26 (B0)
/B1: FFC18.8, U4.27 (B1)
/B2: FFC18.9, U4.28 (B2)
/B3: FFC18.10, U4.29 (B3)
/CDAC: U4.37 (_CDAC)
/CSYNC: FFC18.16, U4.35 (BLANK)
/G0: FFC18.11, U4.30 (G0)
/G1: FFC18.12, U4.31 (G1)
/G2: FFC18.13, U4.32 (G2)
/G3: FFC18.14, U4.33 (G3)
/R0: FFC18.3, U4.22 (R0)
/R1: FFC18.4, U4.23 (R1)
/R2: FFC18.5, U4.24 (R2)
/R3: FFC18.6, U4.25 (R3)
GND: FFC18.15, FFC18.17, FFC18.18, FFC18.MP, U4.40 (GND)

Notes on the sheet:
Use +5V rail from Denise

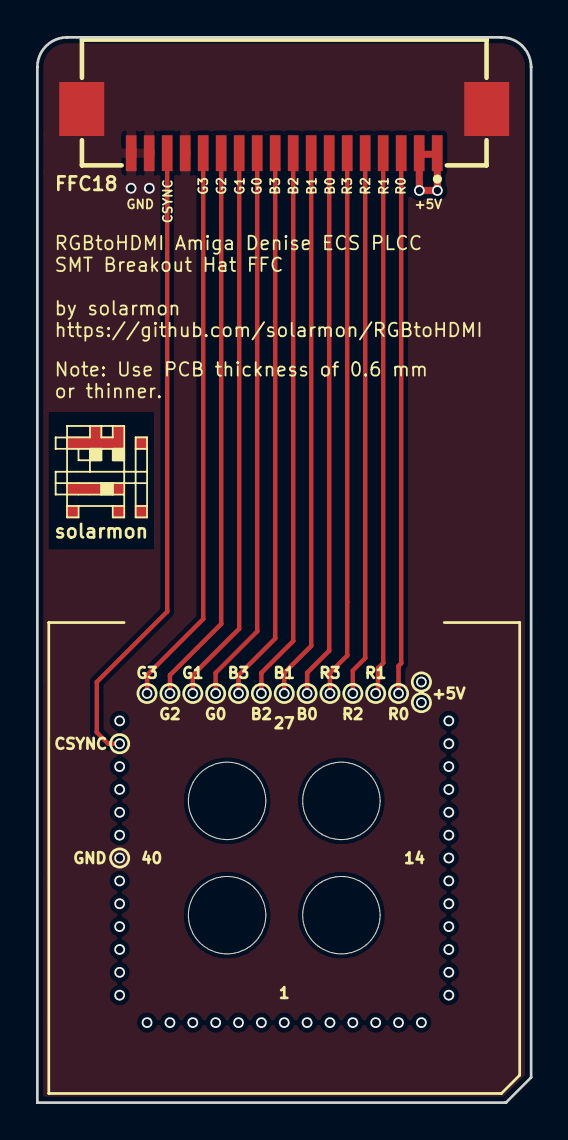
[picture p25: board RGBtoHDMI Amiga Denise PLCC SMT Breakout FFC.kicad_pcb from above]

Board: 2 copper layers, 27.4 x 59.2 mm, 7 parts (1 on the bottom side), 15 nets.

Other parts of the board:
solarmon: solarmon-logo-25mils

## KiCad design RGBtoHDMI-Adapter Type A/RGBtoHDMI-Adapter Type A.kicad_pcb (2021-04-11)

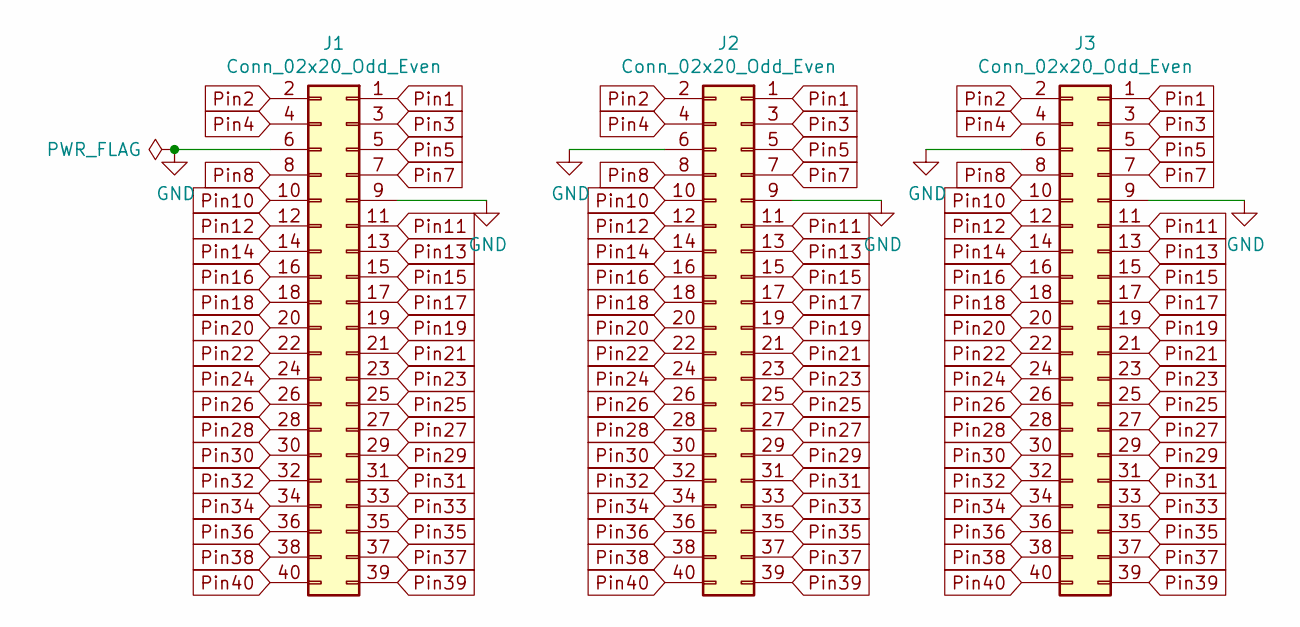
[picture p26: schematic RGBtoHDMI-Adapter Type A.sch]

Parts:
J1: Conn_02x20_Odd_Even; PinHeader_2x20_P2.54mm_Vertical
J2, J3: Conn_02x20_Odd_Even; PinSocket_2x20_P2.54mm_Vertical

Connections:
GND: J1.6, J1.9, J2.6, J2.9, J3.6, J3.9
Pin1: J1.1, J2.1, J3.1
Pin2: J1.2, J2.2, J3.2
Pin3: J1.3, J2.3, J3.3
Pin4: J1.4, J2.4, J3.4
Pin5: J1.5, J2.5, J3.5
Pin7: J1.7, J2.7, J3.7
Pin8: J1.8, J2.8, J3.8
Pin10: J1.10, J2.10, J3.10
Pin11: J1.11, J2.11, J3.11
Pin12: J1.12, J2.12, J3.12
Pin13: J1.13, J2.13, J3.13
Pin14: J1.14, J2.14, J3.14
Pin15: J1.15, J2.15, J3.15
Pin16: J1.16, J2.16, J3.16
Pin17: J1.17, J2.17, J3.17
Pin18: J1.18, J2.18, J3.18
Pin19: J1.19, J2.19, J3.19
Pin20: J1.20, J2.20, J3.20
Pin21: J1.21, J2.21, J3.21
Pin22: J1.22, J2.22, J3.22
Pin23: J1.23, J2.23, J3.23
Pin24: J1.24, J2.24, J3.24
Pin25: J1.25, J2.25, J3.25
Pin26: J1.26, J2.26, J3.26
Pin27: J1.27, J2.27, J3.27
Pin28: J1.28, J2.28, J3.28
Pin29: J1.29, J2.29, J3.29
Pin30: J1.30, J2.30, J3.30
Pin31: J1.31, J2.31, J3.31
Pin32: J1.32, J2.32, J3.32
Pin33: J1.33, J2.33, J3.33
Pin34: J1.34, J2.34, J3.34
Pin35: J1.35, J2.35, J3.35
Pin36: J1.36, J2.36, J3.36
Pin37: J1.37, J2.37, J3.37
Pin38: J1.38, J2.38, J3.38
Pin39: J1.39, J2.39, J3.39
Pin40: J1.40, J2.40, J3.40

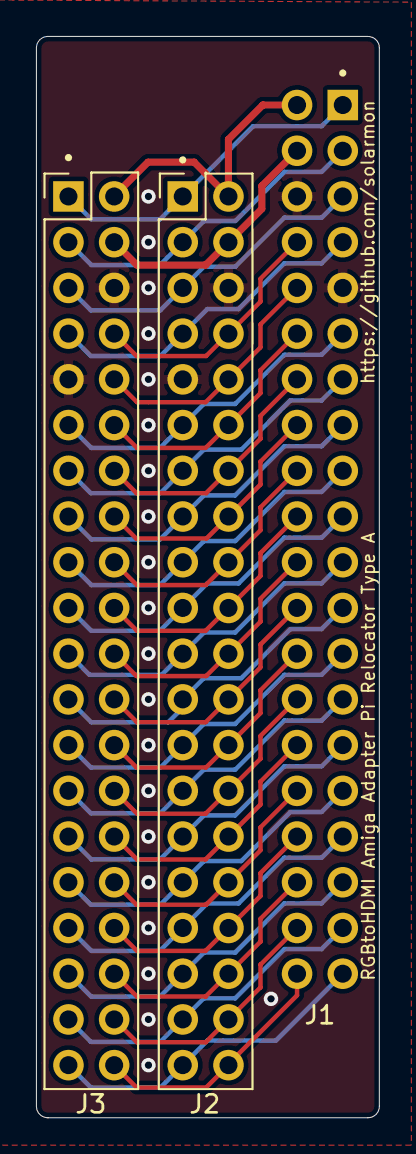
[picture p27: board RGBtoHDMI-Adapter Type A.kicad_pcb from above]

Board: 2 copper layers, 19.0 x 60.1 mm, 3 parts (1 on the bottom side), 39 nets.

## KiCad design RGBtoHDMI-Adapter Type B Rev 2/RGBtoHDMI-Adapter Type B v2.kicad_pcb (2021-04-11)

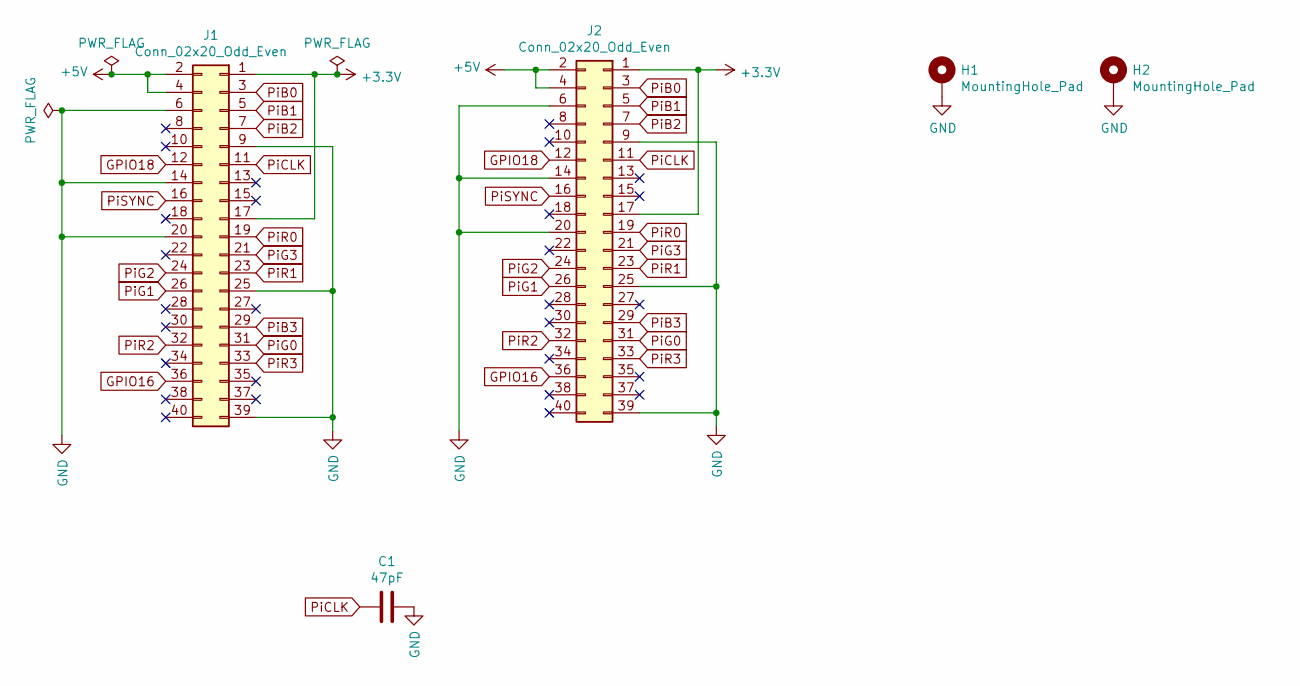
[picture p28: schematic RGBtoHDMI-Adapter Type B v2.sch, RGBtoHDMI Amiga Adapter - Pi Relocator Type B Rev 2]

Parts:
C1: 47pF; C_0805_2012Metric_Pad1.18x1.45mm_HandSolder
H1, H2: MountingHole_Pad; MountingHole_3.2mm_M3_ISO7380_Pad
J1: Conn_02x20_Odd_Even; PinHeader_2x20_P2.54mm_Vertical
J2: Conn_02x20_Odd_Even; PinSocket_2x20_P2.54mm_Vertical

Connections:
+3V3: J1.1, J1.17, J2.1, J2.17
+5V: J1.2, J1.4, J2.2, J2.4
GND: C1.1, H1.1, H2.1, J1.6, J1.9, J1.14, J1.20, J1.25, J1.39, J2.6, J2.9, J2.14, J2.20, J2.25, J2.39
GPIO16: J1.36, J2.36
GPIO18: J1.12, J2.12
PiB0: J1.3, J2.3
PiB1: J1.5, J2.5
PiB2: J1.7, J2.7
PiB3: J1.29, J2.29
PiCLK: C1.2, J1.11, J2.11
PiG0: J1.31, J2.31
PiG1: J1.26, J2.26
PiG2: J1.24, J2.24
PiG3: J1.21, J2.21
PiR0: J1.19, J2.19
PiR1: J1.23, J2.23
PiR2: J1.32, J2.32
PiR3: J1.33, J2.33
PiSYNC: J1.16, J2.16

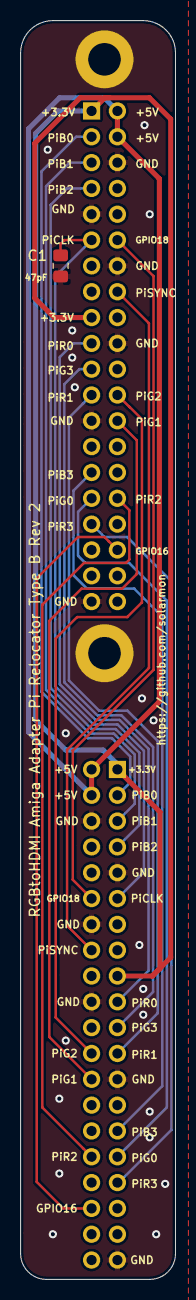
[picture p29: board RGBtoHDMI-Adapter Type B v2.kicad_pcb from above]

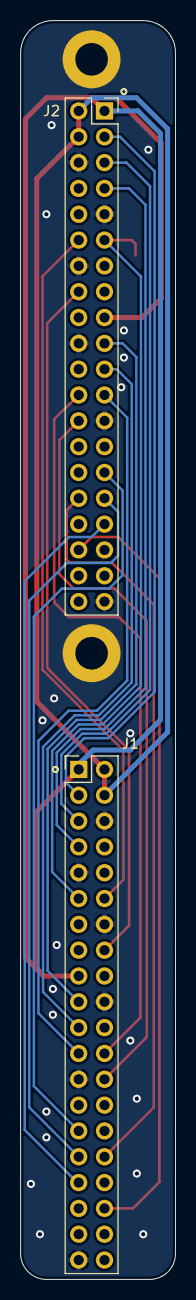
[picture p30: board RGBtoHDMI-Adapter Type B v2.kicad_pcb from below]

Board: 2 copper layers, 15.2 x 123.8 mm, 5 parts (2 on the bottom side), 19 nets.

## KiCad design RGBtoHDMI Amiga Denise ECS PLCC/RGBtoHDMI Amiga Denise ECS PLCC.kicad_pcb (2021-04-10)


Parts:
B1: Conn_01x02; PinHeader_1x02_P2.54mm_Vertical
C1, C2, C3: 100nF; C_0805_2012Metric_Pad1.15x1.40mm_HandSolder
C4: 10uF; C_0805_2012Metric_Pad1.15x1.40mm_HandSolder
H1, H2, H3, H4: MountingHole_Pad; MountingHole_3.2mm_M3_Pad
JRaspberryPiZero1: Conn_02x20_Odd_Even; PinSocket_2x20_P2.54mm_Vertical
P1: Conn_01x02; PinHeader_1x02_P2.54mm_Vertical
R1: 3k3; R_0805_2012Metric_Pad1.15x1.40mm_HandSolder
U1: 74LVC86; SOIC-14_3.9x8.7mm_P1.27mm
U2, U3: 74LVC574; SO-20_12.8x7.5mm_P1.27mm
U4: Denise_ECS_8373; PLCC-52_THT-Socket_Reversed_Hat

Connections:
+3V3: C1.1, C2.1, C3.1, C4.1, JRaspberryPiZero1.1, U1.1, U1.4, U1.14 (VCC), U2.20 (VCC), U3.20 (VCC)
+5V: JRaspberryPiZero1.2, JRaspberryPiZero1.4, P1.1, U4.21 (VCC)
/7M: U1.5, U4.38 (7M)
/B0: U2.9 (D7), U4.26 (B0)
/B1: U2.8 (D6), U4.27 (B1)
/B2: U2.7 (D5), U4.28 (B2)
/B3: U2.6 (D4), U4.29 (B3)
/CSYNC: U2.3 (D1), U4.35 (BLANK)
/G0: U3.3 (D1), U4.30 (G0)
/G1: U3.2 (D0), U4.31 (G1)
/G2: U2.5 (D3), U4.32 (G2)
/G3: U2.4 (D2), U4.33 (G3)
/PiB0: JRaspberryPiZero1.3, U2.12 (Q7)
/PiB1: JRaspberryPiZero1.5, U2.13 (Q6)
/PiB2: JRaspberryPiZero1.7, U2.14 (Q5)
/PiB3: JRaspberryPiZero1.29, U2.15 (Q4)
/PiCLK: JRaspberryPiZero1.11, U1.8, U1.12, U2.2 (D0)
/PiCSYNC: JRaspberryPiZero1.16, U2.18 (Q1)
/PiG0: JRaspberryPiZero1.31, U3.18 (Q1)
/PiG1: JRaspberryPiZero1.26, U3.19 (Q0)
/PiG2: JRaspberryPiZero1.24, U2.16 (Q3)
/PiG3: JRaspberryPiZero1.21, U2.17 (Q2)
/PiR0: JRaspberryPiZero1.19, U3.14 (Q5)
/PiR1: JRaspberryPiZero1.23, U3.15 (Q4)
/PiR2: JRaspberryPiZero1.32, U3.16 (Q3)
/PiR3: JRaspberryPiZero1.33, U3.17 (Q2)
/R0: U3.7 (D5), U4.22 (R0)
/R1: U3.6 (D4), U4.23 (R1)
/R2: U3.5 (D3), U4.24 (R2)
/R3: U3.4 (D2), U4.25 (R3)
GND: B1.1, C1.2, C2.2, C3.2, C4.2, H1.1, H2.1, H3.1, H4.1, JRaspberryPiZero1.6, JRaspberryPiZero1.9, JRaspberryPiZero1.14, JRaspberryPiZero1.20, JRaspberryPiZero1.25, JRaspberryPiZero1.30, JRaspberryPiZero1.34, JRaspberryPiZero1.39, P1.2, R1.2, U1.7 (GND), U1.10, U2.1 (OE), U2.10 (GND), U3.1 (OE), U3.8 (D6), U3.9 (D7), U3.10 (GND), U4.40 (GND)
unnamed: B1.2, JRaspberryPiZero1.36
unnamed: JRaspberryPiZero1.12, R1.1
unnamed: U1.2, U2.19 (Q0)
unnamed: U1.3, U1.9
unnamed: U1.11, U2.11 (Cp), U3.11 (Cp)
unnamed: U1.6, U1.13

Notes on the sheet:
3V3
Ground
GPIO14
GPIO15
GPIO18
GPIO23
GPIO24
GPIO25
GPIO8
GPIO7
GPIO1
GPIO12
GPIO16
GPIO21
GPIO20
GPIO2
GPIO3
GPIO4
GPIO17
GPIO27
GPIO22
GPIO10
GPIO9
GPIO11
GPIO0
GPIO5
GPIO6
GPIO13
GPIO19
GPIO26
74LVC574 requires +3.3V power but has +5V tolerant input pins
Clock
Invert Clock Signal
Use 7Mhz Clock for ECS Denise
Use +3.3V rail from Raspberry Pi
Use +5V rail from Denise
Button for OSD menu
Power Header


Board: 2 copper layers, 65.9 x 40.9 mm, 16 parts (1 on the bottom side), 37 nets.

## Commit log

2021-04-10 Added KiCAD project files
    [RGBtoHDMI Amiga Denise - solarmon-B_Cu.gbr, RGBtoHDMI Amiga Denise - solarmon-B_Mask.gbr, RGBtoHDMI Amiga Denise - solarmon-B_SilkS.gbr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]
2021-04-10 Enabled Pi 3D model
    [RGBtoHDMI Amiga Denise - solarmon.kicad_pcb]
2021-04-11 Added "RGBtoHDMI-Adapter Type C Rev 2"
    [RGBtoHDMI-Adapter Type C Rev 2-B_Cu.gbr, RGBtoHDMI-Adapter Type C Rev 2-B_Mask.gbr, RGBtoHDMI-Adapter Type C Rev 2-B_Paste.gbr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]
2021-04-11 Updated cap value to 47pF
    [RGBtoHDMI-Adapter Type C Rev 2-B_Cu.gbr, RGBtoHDMI-Adapter Type C Rev 2-B_Mask.gbr, RGBtoHDMI-Adapter Type C Rev 2-B_Paste.gbr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]
2021-04-11 Uploaded screenshot of relocator board
2021-04-11 Added "RGBtoHDMI-Adapter Type B Rev 2"
    [RGBtoHDMI-Adapter Type B v2-B_Cu.gbr, RGBtoHDMI-Adapter Type B v2-B_Mask.gbr, RGBtoHDMI-Adapter Type B v2-B_Paste.gbr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]
2021-04-11 Added RGBtoHDMI-Adapter Type A
    [RGBtoHDMI-Adapter Type A-B_Cu.gbr, RGBtoHDMI-Adapter Type A-B_Mask.gbr, RGBtoHDMI-Adapter Type A-B_Paste.gbr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]
2021-04-27 Added rev 2 TSSOP and SOIC boards
    [RGBtoHDMI Amiga Denise - solarmon - Rev 2 - SOIC-B_Cu.gbr, RGBtoHDMI Amiga Denise - solarmon - Rev 2 - SOIC-B_Mask.gbr, RGBtoHDMI Amiga Denise - solarmon - Rev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]
2021-04-27 Added RGBtoHDMI Amiga Denise - v2++ by solarmon - Rev 2
    [RGBtoHDMI Amiga Denise - v2++ Rev 2 by solarmon-B_Cu.gbr, RGBtoHDMI Amiga Denise - v2++ Rev 2 by solarmon-B_Mask.gbr, RGBtoHDMI Amiga Denise - v2++ Rev 2 by so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]
2021-04-27 Corrected U1 label orientation
    [RGBtoHDMI Amiga Denise - v2++ Rev 2 by solarmon-B_Cu.gbr, RGBtoHDMI Amiga Denise - v2++ Rev 2 by solarmon-B_Mask.gbr, RGBtoHDMI Amiga Denise - v2++ Rev 2 by so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]
2021-04-28 Added warning about SMD socket header for Pi Zero
2021-06-05 Added CPLD based designs
    Added CPLD based designs:
    * RGBtoHDMI Amiga Denise CPLD FFC
    * RGBtoHDMI Amiga Denise DIP Breakout FFC
    * RGBtoHDMI Amiga Denise DIP CPLD
    * RGBtoHDMI Amiga Denise PLCC SMT Breakout FFC
    [RGBtoHDMI Amiga Denise CPLD FFC-B_Cu.gbr, RGBtoHDMI Amiga Denise CPLD FFC-B_Mask.gbr, RGBtoHDMI Amiga Denise CPLD FFC-B_Paste.gbr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]
2021-07-27 Added top image with Pi
    [RGBtoHDMI Amiga Denise DIP CPLD.kicad_pcb]
2021-08-15 Added Rev 1.1 versions
    [RGBtoHDMI Amiga Denise CPLD FFC Rev 1.1-B_Cu.gbr, RGBtoHDMI Amiga Denise CPLD FFC Rev 1.1-B_Mask.gbr, RGBtoHDMI Amiga Denise CPLD FFC Rev 1.1-B_Paste.gbr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]
2021-08-15 Updated for CPLD Rev 1.1 boards
